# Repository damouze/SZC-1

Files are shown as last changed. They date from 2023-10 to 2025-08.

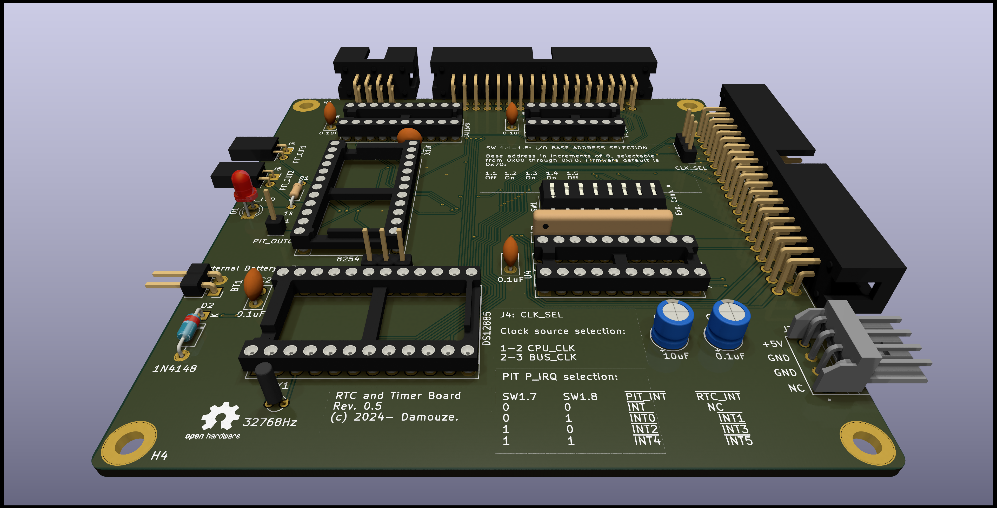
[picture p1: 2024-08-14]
pics/renderings/rtc_timer_board_front.png

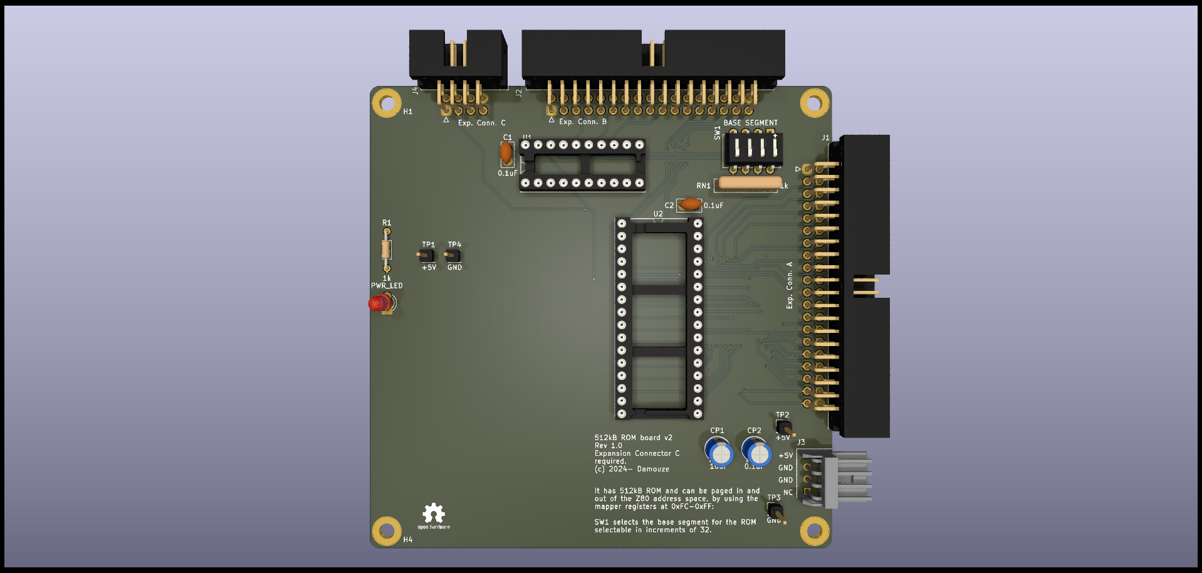
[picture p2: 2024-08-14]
pics/renderings/rom_board_512kB_v2_top.png

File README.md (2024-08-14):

# The Stackable Z80 Computer

A layman's attempt at designing a modular, stackable Z80 computer.

## Disclaimer

Let me start by pointing out that I am not an electronic engineer. Everything I know
about electronics I learned from the internet and from two electronic design courses
during my university days, and nearly all of it is theoretical. I am really more of a
software person who decided at one point in his not-so-distant past that it might be
fun to start learning to design (digital) electronic circuits. 

That said, this is not my first KiCAD project. 

The designs in this repository are bound to have many, many flaws, and I would love to
hear about them from you. Just keep in mind that I do have a day job and that it takes
precedence if I do not respond to them within a day. As a person without an actual
background in electronic design I am sure I am making assumptions about components in
the design that are incorrect or otherwise potentially troublesome. 

Ok, enough ranting. Let's have a look at it.

## Physical description

In principle, the Stackable Z80 computer is more an idea than an actual design. As such
it is built around the following concepts:

- The board dimensions are 95.25mm x 95.25mm (3.75" x 3.75")
- There are four main connectors:
    - Expansion Connector A (2x20 pins, IDC)
	- Expansion Connector B (2x17 pins, IDC)
	- Expansion Connector C (2x4 pins, IDC)
	- Power Connector (2x10 pins, IDC)
- Each board can be stacked on top of another through the use of standoffs

Expansion Connector A is standardized; it contains most, if not all, of the relevant
Z80 signals, such as the address bus (A0-A15), the data bus (D0-D7), control signals
like /INT, /RESET, etc, and both a CPU_CLK and a BUS_CLK signal (they may differ, but
the former should then always be an integer multiple of the latter). All address, data
and control lines should have pull-ups or pull-downs on at least one board, so as to
prevent undesirable current from flowing between two devices asserting the bus at the
same time. They are also buffered. Pins 1 and 40 are connected to ground.

Expansion Connector B is partly standardized; the uneven numbered pins are used for 8
interrupt lines (/INT0-/INT7), as well as 8 more address lines (MA14-A21). Pins 1 and 
34 are connected to ground. The remaining pins, all even, are defined as USER0-USER15,
or in other words, user defined. 

Expansion Connector C contains the extra bus signals provided by the Z80 CPU board with
an extended bus (cpu_board_ext_bus+v2). It provides 5 new signals: /IOR, /IOW, /MEMR, /MEMW
and /INTA. These can be used to simplify the designs of future boards. In addition they
also provide the necessary signals for interfacing with an Intel 8259 Programmable
Interrupt Controller. 

The Power Connector is standardized around the 20-pins ATX power supply connector, and indeed
the Power Board does contain one, but power to the CPU board is provided through an IDC header.
The rationale behind this is that power to the CPU board is is delivered from the power supply 
through the power board, which has a front panel header and which in turn distributes power to
the CPU board through the aforementioned 2x10 pins IDC header.

Power delivery to all other boards is standardized around the old-fashioned floppy 
connector (TE_171826-4). Only +12V and +5V are available. +5VSB (standby power) and 3.3V
should be delivered separately, for instance from the power board.

## Minimal configuration (top to bottom)

- Serial I/O board
- ROM/RAM board
- The "even simpler Z80" board
- Power board V2

This will provide a basic Z80 system with serial I/O support. The serial I/O board should
be configured to use /INT as its interrupt line and use 0x80 as its I/O base address.

The system will have 32kB of ROM, as well as 96kB of RAM, able to be paged in or out of the
Z80 address space as needed in segments of 16kB. 

Expansion Bus B is not used in this configuration.

## A more advance configuration (top to bottom)

- Serial I/O board
- ROM/RAM board v2
- CPU board with expansion Connector C
- Power board V2

This will provide a slightly more advanced Z80 system with serial I/O support. The serial I/O
board should be configured to use /INT as its interrupt line and use 0x80 as its I/O
base address. The ROM/RAM board should be configured for Bank 0. 

This system will have 512kB of Flash ROM and 1536kB of SRAM. Segments 0-31 will be ROM, 
segments 32-127 will be RAM. Segments 128-255 will be available for add-on boards with
their own ROM or RAM or which use memory mapped I/O. 

## Repository layout
 
The repository is laid out as follows:

- boards/core contains the core boards
    - even_simpler_z80: the basic, bare bones Z80 board; just the CPU, some buffers/latches and a clock generator
	- power_board: the power delivery board
	- power_board_v2: and updated version of the power delivery board, with power-on circuitry onboard
	- rom_ram_board: a board that provides 32kB of ROM and 96kB of RAM, able to be paged in and out as needed
	- serial_io_board: a board that provides a RS232 interface for outside communication
- boards/extra contains some extra board designs
    - 8259_pic_board: 8259 Interrupt Controller Board for the SZC-1; requires Expansion Connector C
    - audio_board: SSG Audio Board for the SZC-1, providing SSG sound support
	- cpu_board_ext_bus_v2: new and improved CPU board providing Expansion Connector C and an on-board memory mapper
    - diag_board: a basic diagnostics board, providing a 2-digit 7-segment display accessible through I/O port 0xb8
	- ide_board: IDE Board for the SZC-1, inspired by the Beer IDE interface for the MSX
	- mmu_board: a preliminary design for a Z80 MMU built around a ATF1502/1504 CPLD (*work in progress*)
	- rom_ram_board_2MB: a board that provides 512kB of flash ROM and 1536kB of RAM, able to be paged in and out as needed
	- rom_ram_board_128kB_v2: another board that provides 32kB of EEPROM and 96kB of RAM; requires Expansion Connector C
	- rom_ram_board_v2: another board that provides 512kB of flash ROM and 1536kB of RAM; requires Expansion Connector C
	- simple_z80: the original Z80 board, CPU, buffers/latches and a LS74xx based IM2 interrupt controller
- boards/msx_compat contains boards to provide MSX compatibility (*work in progress*)
    - msx_rom_board: a board that houses to 32kB EEPROM sockets for MSX compatible ROMs (requires the ppi_slot_select_expanded board)
    - msx_rom_ram_board: a board with 512kB flash ROM and 1MB SRAM (requires the ppi_slot_select_expanded board)
	- ppi_slot_select: a board that provides MSX compatible slot select registers as well as 16 GPIO pins
	- ppi_slot_select_expanded: as ppi_slot_select, but also contains an expanded slot select register
- digital contains experiments made in Digital to work out some concepts
- doc: contains documentation and other reference material
- ibom: interactive BOMs for the boards
- pics: 
    - renderings: contains 3D renderings of most of the boards
	- photos: contains photos of PCBs and assembled boards
- verilog: contains verilog output from Digital for the experiments in the *digital* folder.

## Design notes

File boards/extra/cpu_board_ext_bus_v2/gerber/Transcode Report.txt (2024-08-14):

   ---- Transcoding 'C:\Users\dmouse\ownCloud\Projects\KiCAD\SZC-1\boards\extra\cpu_board_ext_bus_v2\gerber\cpu_board_ext_bus_v2-B_Cu.gbr' ----   Fri May 10 12:37:28 2024

D28   --> D100
D29   --> D101
-----------------------------------------------------------------

   ---- Transcoding 'C:\Users\dmouse\ownCloud\Projects\KiCAD\SZC-1\boards\extra\cpu_board_ext_bus_v2\gerber\cpu_board_ext_bus_v2-F_Silkscreen.gbr' ----   Fri May 10 12:37:28 2024

D11   --> D102
D12   --> D103
D13   --> D104
-----------------------------------------------------------------

   ---- Transcoding 'C:\Users\dmouse\ownCloud\Projects\KiCAD\SZC-1\boards\extra\cpu_board_ext_bus_v2\gerber\cpu_board_ext_bus_v2-User_Comments.gbr' ----   Fri May 10 12:37:28 2024

D10   --> D105
-----------------------------------------------------------------

   ---- Transcoding 'C:\Users\dmouse\ownCloud\Projects\KiCAD\SZC-1\boards\extra\cpu_board_ext_bus_v2\gerber\cpu_board_ext_bus_v2-Edge_Cuts.gbr' ----   Fri May 10 12:37:28 2024

D10   --> D106
-----------------------------------------------------------------

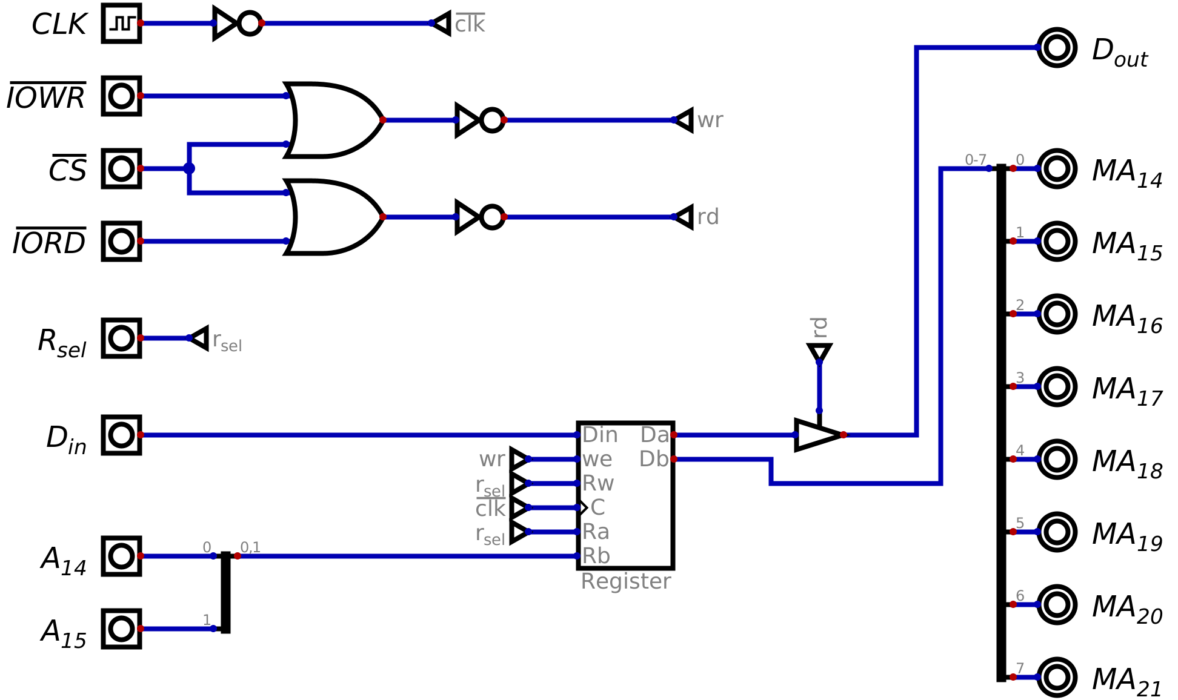
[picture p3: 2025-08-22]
pics/renderings/z80_mmu.png

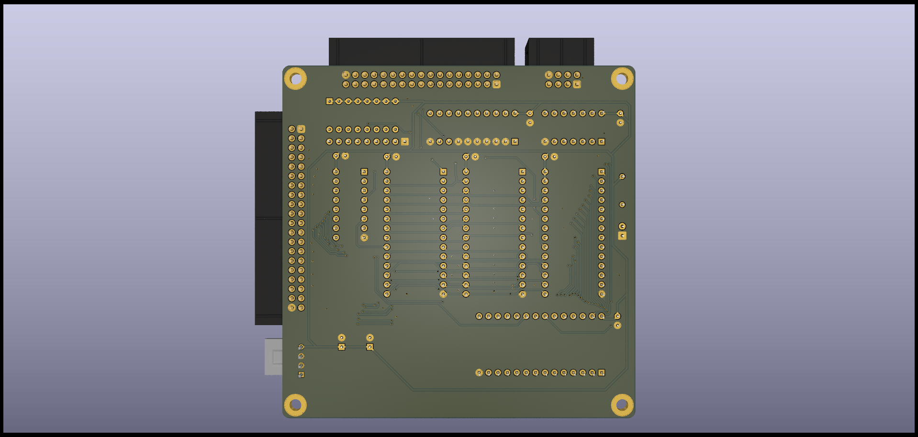
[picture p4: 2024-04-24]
pics/renderings/rom_ram_board_128kB_v2_bottom.png

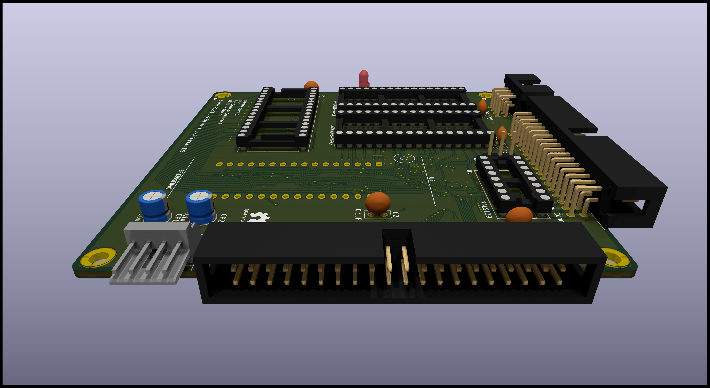
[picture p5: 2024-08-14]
pics/renderings/rom_ram_board_v3_right.png

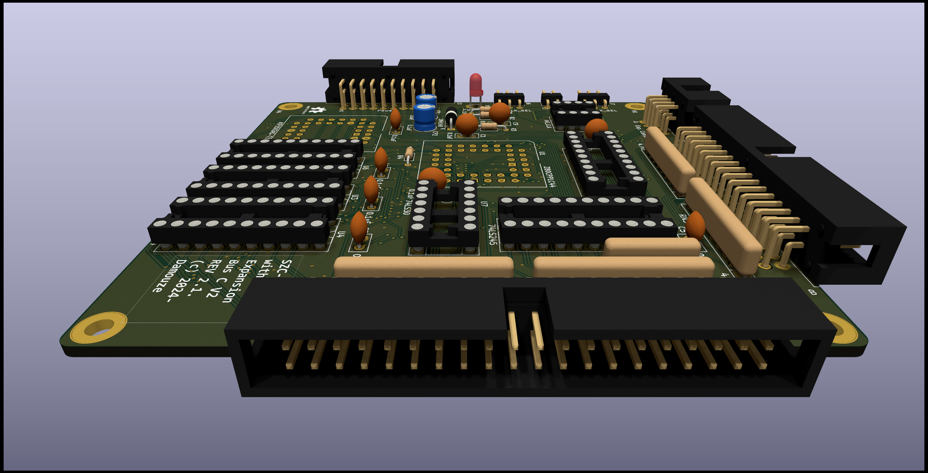
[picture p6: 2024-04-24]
pics/renderings/cpu_board_ext_bus_v2_right.png

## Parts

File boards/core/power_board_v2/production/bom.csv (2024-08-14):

Designator | Footprint | Quantity | Value | LCSC Part #
D1 | LED_D3.0mm | 1 | PWR_LED
D2 | LED_D3.0mm | 1 | SB_LED
H1, H2, H3, H4 | MountingHole_3.2mm_M3_ISO7380_Pad | 4 | MountingHole_Pad
J1 | IDC-Header_2x20_P2.54mm_Horizontal | 1 | Exp. Conn. A
J2 | IDC-Header_2x17_P2.54mm_Horizontal | 1 | Exp. Conn. B
J3 | IDC-Header_2x10_P2.54mm_Horizontal | 1 | Power
J4 | PinHeader_2x06_P2.54mm_Horizontal | 1 | Front Panel Connector
J5 | Molex_Mini-Fit_Jr_5569-20A1_2x10_P4.20mm_Horizontal | 1 | ATX-20
R1, R2, R3 | R_Axial_DIN0204_L3.6mm_D1.6mm_P7.62mm_Horizontal | 3 | 470

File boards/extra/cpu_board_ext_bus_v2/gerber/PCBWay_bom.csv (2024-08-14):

designator | quantity | value | pack | mpn | mount_type
C1, C2, C3, C4, C5, C6, C7, C8, C9 | 9 | 0.1uF | C_Disc_D5.0mm_W2.5mm_P2.50mm | FG28X7R1H104KNT06 | tht
CP1 | 1 | 10uF | CP_Radial_D5.0mm_P2.50mm | ECA1HM100I | tht
CP2 | 1 | 0.1uF | CP_Radial_D5.0mm_P2.50mm | KS104M050C07RR0VH2FP0 | tht
D1 | 1 | PWR_LED | LED_D3.0mm | HLMP-1700 | tht
D2 | 1 | 1N4148 | D_DO-35_SOD27_P7.62mm_Horizontal | 1N4148TA | tht
H1, H2, H3, H4 | 4 | MountingHole_Pad | MountingHole_3.2mm_M3_ISO7380_Pad |  | tht
J1 | 1 | Exp. Conn. A | IDC-Header_2x20_P2.54mm_Horizontal | X9555WR-2x20-6TV01 | tht
J2 | 1 | Exp. Conn. B | IDC-Header_2x17_P2.54mm_Horizontal | X9555WR-2x17-6TV01 | tht
J3 | 1 | Power | IDC-Header_2x10_P2.54mm_Horizontal | X9555WR-2x10-6TV01 | tht
J4 | 1 | Exp. Conn. C | IDC-Header_2x04_P2.54mm_Horizontal | 75867-132LF | tht
J5 | 1 | EXT_CLK | PinHeader_1x02_P2.54mm_Horizontal | PZ254R-11-02P | tht
J6 | 1 | CPU_CLK_SEL | PinHeader_1x03_P2.54mm_Horizontal | PZ254R-11-03P | tht
J7 | 1 | BUS_CLK_SEL | PinHeader_1x03_P2.54mm_Horizontal | PZ254R-11-03P | tht
R1 | 1 | 1k | R_Axial_DIN0204_L3.6mm_D1.6mm_P7.62mm_Horizontal | MFR2WSFTE73-1K | tht
R2, R3 | 2 | 10k | R_Axial_DIN0204_L3.6mm_D1.6mm_P7.62mm_Horizontal | MFR3WSFTE73-10K | tht
R4 | 1 | 4.7k | R_Axial_DIN0204_L3.6mm_D1.6mm_P7.62mm_Horizontal | MF0207FTE52-4K7 | tht
RN1, RN2, RN3, RN4 | 4 | 4.7k | R_Array_SIP9 | A09-472JP | tht
RN5 | 1 | 4.7k | R_Array_SIP5 | A05-472JP | tht
U1 | 1 | Z80CPPLC44 | PLCC-44_THT-Socket | DS1032-44SDKT1A | tht
U2 | 1 | GAL16V8 | DIP-20_W7.62mm_Socket | 1-2199298-6 | tht
U3, U4, U6 | 3 | 74LS244 | DIP-20_W7.62mm_Socket | 1-2199298-6 | tht
U5 | 1 | 74LS245 | DIP-20_W7.62mm_Socket | 1-2199298-6 | tht
U7 | 1 | 74LS30 | DIP-14_W7.62mm_Socket | 1-2199298-3 | tht
U8 | 1 | ATF1502AS-7JX44 | PLCC-44_THT-Socket | DS1032-44SDKT1A | tht
X1 | 1 | INT_CLK | DIP-8_W7.62mm_Socket | 1-2199298-2 | tht

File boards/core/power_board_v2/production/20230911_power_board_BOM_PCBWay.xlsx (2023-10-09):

 |  |  | xxxx xxxx xxxxx xxPCS BOM (Sample Bill of Materials)
Item # | *Designator | *Qty | Manufacturer | *Mfg Part # | Description / Value | *Package/Footprint | Type | Your Instructions / Notes
1 | D1 | 1 | Broadcom/AVAGO | HLMP-1700 | -40℃~+100℃ 626nm Red 14mW Plugin,D=3.2mm Light Emitting Diodes (LED) ROHS | LED_D3.0mm | thru-hole
2 | D2 | 1 | Broadcom/AVAGO | HLMP-1700 | -40℃~+100℃ 626nm Red 14mW Plugin,D=3.2mm Light Emitting Diodes (LED) ROHS | LED_D3.0mm | thru-hole
3 | H1, H2, H3, H4 | 4 | N/A | N/A | MountingHole_3.2mm_M3_ISO7380_Pad | N/A | N/A | Part of the board layout
4 | J1 | 1 | XKB Connectivity | X9555WR-2x20-6TV01 | 2x20P 2 Gold 2.54mm Male pin 2.54mm 20 260℃ -25℃~+85℃ Brass 3A Shrouded Push-Pull,P=2.54mm Wire To Board / Wire To Wire Connector ROHS | IDC-Header_2x20_P2.54mm_Horizontal | thru-hole
5 | J2 | 1 | XKB Connectivity | X9555WR-2x17-6TV01 | 2x17P 2 Gold 2.54mm Male pin 2.54mm 17 260℃ -25℃~+85℃ Brass 3A Shrouded Push-Pull,P=2.54mm Wire To Board / Wire To Wire Connector ROHS | IDC-Header_2x17_P2.54mm_Horizontal | thru-hole
6 | J3 | 1 | XKB Connectivity | X9555WR-2x10-6TV01 | 2x10P 2 Gold 2.54mm Male pin 2.54mm 10 260℃ -25℃~+85℃ Brass 3A Shrouded Push-Pull,P=2.54mm Wire To Board / Wire To Wire Connector ROHS | IDC-Header_2x10_P2.54mm_Horizontal | thru-hole
7 | J4 | 1 | XFCN | PZ254R-12-12P | Shrouded Square Pins 2.5mm 12P 6mm -40℃~+105℃ 2.54mm 双排 Black Brass 2x6P 2.54mm Push-Pull,P=2.54mm Pin Headers ROHS | PinHeader_2x06_P2.54mm_Horizontal | thru-hole
8 | J5 | 1 | Molex | 39301200 | 2x10P 2 4.2mm Female pin 4.2mm 10 Shrouded Push-Pull,P=4.2mm Wire To Board / Wire To Wire Connector ROHS | Molex_Mini-Fit_Jr_5569-20A1_2x10_P4.20mm_Horizontal | thru-hole
9 | R1, R2, R3 | 3 | YAGEO | MFR-25FRF52-1K | Metal Film Resistors 1kΩ 250mW ±100ppm/℃ ±1% Plugin Through Hole Resistors ROHS | R_Axial_DIN0204_L3.6mm_D1.6mm_P7.62mm_Horizontal | thru-hole
10
11
12
13
14
15
Need a quick and accurante quote? Need an efficient production? Please read SMT Ordering Necessary Files & Info in 1 minute. Thank you very much! (https://www.pcbway.com/smt_ordering_guide.html)
Click for Instructions on How to Create a BOM (https://www.pcbway.com/blog/PCB_Assembly/How_to_Build_a_BOM__Bill_Of_Materials_.html)

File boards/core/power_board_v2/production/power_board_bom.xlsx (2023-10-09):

Designator | Footprint | Quantity | Value | LCSC Part # | DIGIKEY Part # | LCSC Piece Price | Digikey Piece Price | PCBWay Piece Price | LCSC Price | Digikey Price | PCBWay Price
D1 | LED_D3.0mm | 1 | PWR_LED | C188720 | 516-1308-ND | €0.59 | €0.59 |  | €0.59 | €0.59
D2 | LED_D3.0mm | 1 | SB_LED | C188720 | 516-1308-ND | €0.59 | €0.59 |  | €0.59 | €0.59
H1, H2, H3, H4 | MountingHole_3.2mm_M3_ISO7380_Pad | 4 | MountingHole_Pad | N/A | N/A |  |  |  | €0.00 | €0.00
J1 | IDC-Header_2x20_P2.54mm_Horizontal | 1 | Exp. Conn. A | C2682225 | 609-3345-ND | €0.41 | €1.29 |  | €0.41 | €1.29
J2 | IDC-Header_2x17_P2.54mm_Horizontal | 1 | Exp. Conn. B | C2682224 | A97489-ND | €0.35 | €3.60 |  | €0.35 | €3.60
J3 | IDC-Header_2x10_P2.54mm_Horizontal | 1 | Power | C2884508 | A33184-ND | €0.21 | €2.50 |  | €0.21 | €2.50
J4 | PinHeader_2x06_P2.54mm_Horizontal | 1 | Front Panel Connector | C492434 | 9-103326-0-06 | €0.07 | €1.22 |  | €0.07 | €1.22
J5 | Molex_Mini-Fit_Jr_5569-20A1_2x10_P4.20mm_Horizontal | 1 | ATX-20 | C485578 | WM1360-ND | €2.75 | €3.31 |  | €2.75 | €3.31
R1, R2, R3 | R_Axial_DIN0204_L3.6mm_D1.6mm_P7.62mm_Horizontal | 3 | 1k | C3424075 | 13-MFR-25FRF52-1KCT-ND | €0.01 | €0.09 |  | €0.04 | €0.27
Component Cost |  |  |  |  |  |  |  |  | €15.03
PCB Production |  | 5 |  |  |  |  |  | €1.00 |  |  | €5.00
PCB Assembly |  | 3 |  |  |  |  |  | €10.00 |  |  | €30.00
TOTAL w. LCSC Parts |  |  |  |  |  |  |  |  | €50.03
TOTAL w. Digikey Parts |  |  |  |  |  |  |  |  |  | €75.11
Costs per assembled board |  |  |  |  |  |  |  |  | €16.68 | €25.04

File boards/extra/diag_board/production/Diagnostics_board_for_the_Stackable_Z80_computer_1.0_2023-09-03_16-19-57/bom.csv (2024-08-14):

Designator | Footprint | Quantity | Value | LCSC Part #
C1, C2, C3, C4, C5, C6, C7 | C_Disc_D5.0mm_W2.5mm_P2.50mm | 7 | 0.1uF
CP1 | CP_Radial_D5.0mm_P2.50mm | 1 | 10uF
CP2 | CP_Radial_D5.0mm_P2.50mm | 1 | 0.1uF
D1 | LED_D3.0mm | 1 | PWR_LED
D10 | LED_D3.0mm | 1 | LED_12V
D11 | LED_D3.0mm | 1 | LED_-12V
D2 | LED_D3.0mm | 1 | LED_3.3V
D3, D4 | LED_D3.0mm | 2 | LED_3.3V2
D5 | LED_D3.0mm | 1 | LED_5V
D6 | LED_D3.0mm | 1 | LED_5V2
D7 | LED_D3.0mm | 1 | LED_5V3
D8 | LED_D3.0mm | 1 | LED_5V4
D9 | LED_D3.0mm | 1 | LED_5VSB
H1, H2, H3, H4 | MountingHole_3.2mm_M3_ISO7380_Pad | 4 | MountingHole_Pad
J1 | IDC-Header_2x20_P2.54mm_Horizontal | 1 | Exp. Conn. A
J3 | IDC-Header_2x10_P2.54mm_Horizontal | 1 | Power
J4 | PinHeader_2x10_P2.54mm_Horizontal | 1 | 7SEG_LED_DISPLAY
R1 | R_Axial_DIN0204_L3.6mm_D1.6mm_P7.62mm_Horizontal | 1 | 470
R10, R11 | R_Axial_DIN0204_L3.6mm_D1.6mm_P7.62mm_Horizontal | 2 | 2.4k
R2, R3, R4 | R_Axial_DIN0204_L3.6mm_D1.6mm_P7.62mm_Horizontal | 3 | 660
R5, R6, R7, R8, R9 | R_Axial_DIN0204_L3.6mm_D1.6mm_P7.62mm_Horizontal | 5 | 1k
RN1, RN2 | R_Array_SIP5 | 2 | 1k
U1 | DIP-20_W7.62mm_Socket | 1 | 74LS688
U2 | DIP-14_W7.62mm_Socket | 1 | 74LS04
U3 | DIP-14_W7.62mm_Socket | 1 | 74LS74
U4 | DIP-14_W7.62mm_Socket | 1 | 74LS02
U5 | DIP-20_W7.62mm_Socket | 1 | 74LS573
U6, U7 | DIP-20_W7.62mm_Socket | 2 | GAL16V8

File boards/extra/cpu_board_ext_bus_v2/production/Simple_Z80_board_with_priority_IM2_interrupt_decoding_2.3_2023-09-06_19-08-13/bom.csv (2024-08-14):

Designator | Footprint | Quantity | Value | LCSC Part #
C1, C10, C12, C2, C3, C4, C5, C6, C7, C8, C9 | C_Disc_D5.0mm_W2.5mm_P2.50mm | 11 | 0.1uF
CP1 | CP_Radial_D5.0mm_P2.50mm | 1 | 10uF
CP2 | CP_Radial_D5.0mm_P2.50mm | 1 | 0.1uF
D1 | LED_D3.0mm | 1 | PWR_LED
D2 | D_A-405_P7.62mm_Horizontal | 1 | D
H1, H2, H3, H4 | MountingHole_3.2mm_M3_ISO7380_Pad | 4 | MountingHole_Pad
J1 | IDC-Header_2x20_P2.54mm_Horizontal | 1 | Exp. Conn. A
J2 | IDC-Header_2x17_P2.54mm_Horizontal | 1 | Exp. Conn. B
J3 | IDC-Header_2x10_P2.54mm_Horizontal | 1 | Power
J4 | PinHeader_1x02_P2.54mm_Horizontal | 1 | EXT_CLK
J5 | PinHeader_1x03_P2.54mm_Horizontal | 1 | CPU_CLK_SEL
J6 | PinHeader_1x03_P2.54mm_Horizontal | 1 | BUS_CLK_SEL
R1 | R_Axial_DIN0204_L3.6mm_D1.6mm_P7.62mm_Horizontal | 1 | 470
R2, R3 | R_Axial_DIN0204_L3.6mm_D1.6mm_P7.62mm_Horizontal | 2 | 10k
RN1, RN2, RN3, RN4 | R_Array_SIP9 | 4 | 4.7k
RN5 | R_Array_SIP5 | 1 | 4.7k
U1 | DIP-14_W7.62mm_Socket | 1 | 74LS32
U10 | DIP-20_W7.62mm_Socket | 1 | 74LS245
U2 | DIP-16_W7.62mm_Socket | 1 | 74LS148
U3 | DIP-20_W7.62mm_Socket | 1 | 74LS573
U4 | DIP-14_W7.62mm_Socket | 1 | 74LS04
U5 | PLCC-44_THT-Socket | 1 | Z80CPPLC44
U6 | DIP-14_W7.62mm_Socket | 1 | 74LS08
U7, U8, U9 | DIP-20_W7.62mm_Socket | 3 | 74LS244
X1 | DIP-8_W7.62mm_Socket | 1 | INT_CLK

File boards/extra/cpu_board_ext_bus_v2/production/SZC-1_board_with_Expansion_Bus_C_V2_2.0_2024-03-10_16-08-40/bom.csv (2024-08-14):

Designator | Footprint | Quantity | Value | LCSC Part #
C1, C2, C3, C4, C5, C6, C7, C8, C9 | C_Disc_D5.0mm_W2.5mm_P2.50mm | 9 | 0.1uF
CP1 | CP_Radial_D5.0mm_P2.50mm | 1 | 10uF
CP2 | CP_Radial_D5.0mm_P2.50mm | 1 | 0.1uF
D1 | LED_D3.0mm | 1 | PWR_LED
D2 | D_A-405_P7.62mm_Horizontal | 1 | 1N4148
H1, H2, H3, H4 | MountingHole_3.2mm_M3_ISO7380_Pad | 4 | MountingHole_Pad
J1 | IDC-Header_2x20_P2.54mm_Horizontal | 1 | Exp. Conn. A
J2 | IDC-Header_2x17_P2.54mm_Horizontal | 1 | Exp. Conn. B
J3 | IDC-Header_2x10_P2.54mm_Horizontal | 1 | Power
J4 | IDC-Header_2x04_P2.54mm_Horizontal | 1 | Exp. Conn. C
J5 | PinHeader_1x02_P2.54mm_Horizontal | 1 | EXT_CLK
J6 | PinHeader_1x03_P2.54mm_Horizontal | 1 | CPU_CLK_SEL
J7 | PinHeader_1x03_P2.54mm_Horizontal | 1 | BUS_CLK_SEL
R1 | R_Axial_DIN0204_L3.6mm_D1.6mm_P7.62mm_Horizontal | 1 | 1k
R2, R3 | R_Axial_DIN0204_L3.6mm_D1.6mm_P7.62mm_Horizontal | 2 | 10k
R4 | R_Axial_DIN0204_L3.6mm_D1.6mm_P7.62mm_Horizontal | 1 | 4.7k
RN1, RN2, RN3, RN4 | R_Array_SIP9 | 4 | 4.7k
RN5 | R_Array_SIP5 | 1 | 4.7k
U1 | PLCC-44_THT-Socket | 1 | Z80CPPLC44
U2 | DIP-20_W7.62mm_Socket | 1 | GAL16V8
U3, U4, U6 | DIP-20_W7.62mm_Socket | 3 | 74LS244
U5 | DIP-20_W7.62mm_Socket | 1 | 74LS245
U7 | DIP-14_W7.62mm_Socket | 1 | 74LS30
U8 | PLCC-44_THT-Socket | 1 | ATF1502AS-7JX44
X1 | DIP-8_W7.62mm_Socket | 1 | INT_CLK

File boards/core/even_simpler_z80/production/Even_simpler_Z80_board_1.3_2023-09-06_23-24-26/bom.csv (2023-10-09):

Designator | Footprint | Quantity | Value | LCSC Part #
C1, C10, C2, C3, C4, C5, C6, C7, C8 | C_Disc_D5.0mm_W2.5mm_P2.50mm | 9 | 0.1uF
CP1 | CP_Radial_D5.0mm_P2.50mm | 1 | 10uF
CP2 | CP_Radial_D5.0mm_P2.50mm | 1 | 0.1uF
D1 | LED_D3.0mm | 1 | PWR_LED
D2 | D_A-405_P7.62mm_Horizontal | 1 | 1N4148
H1, H2, H3, H4 | MountingHole_3.2mm_M3_ISO7380_Pad | 4 | MountingHole_Pad
J1 | IDC-Header_2x20_P2.54mm_Horizontal | 1 | Exp. Conn. A
J2 | IDC-Header_2x17_P2.54mm_Horizontal | 1 | Exp. Conn. B
J3 | IDC-Header_2x10_P2.54mm_Horizontal | 1 | Power
J4 | PinHeader_1x02_P2.54mm_Horizontal | 1 | EXT_CLK
J5 | PinHeader_1x03_P2.54mm_Horizontal | 1 | CPU_CLK_SEL
J6 | PinHeader_1x03_P2.54mm_Horizontal | 1 | BUS_CLK_SEL
R1 | R_Axial_DIN0204_L3.6mm_D1.6mm_P7.62mm_Horizontal | 1 | 1k
R2, R3 | R_Axial_DIN0204_L3.6mm_D1.6mm_P7.62mm_Horizontal | 2 | 10k
RN1, RN2, RN3, RN4 | R_Array_SIP9 | 4 | 4.7k
RN5 | R_Array_SIP5 | 1 | 4.7k
U1 | PLCC-44_THT-Socket | 1 | Z80CPPLC44
U2 | DIP-14_W7.62mm_Socket | 1 | 74LS32
U3, U5, U6 | DIP-20_W7.62mm_Socket | 3 | 74LS244
U4 | DIP-14_W7.62mm_Socket | 1 | 74LS04
U7 | DIP-14_W7.62mm_Socket | 1 | 74LS08
U8 | DIP-20_W7.62mm_Socket | 1 | 74LS245
X1 | DIP-8_W7.62mm_Socket | 1 | INT_CLK

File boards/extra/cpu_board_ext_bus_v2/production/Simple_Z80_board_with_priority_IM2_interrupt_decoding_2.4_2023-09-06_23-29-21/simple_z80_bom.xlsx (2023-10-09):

Designator | Footprint | Quantity | Value | LCSC Part # | Digikey Part #
C1, C10, C12, C2, C3, C4, C5, C6, C7, C8, C9 | C_Disc_D5.0mm_W2.5mm_P2.50mm | 11 | 0.1uF | C444742 | 478-7358-1-ND
CP1 | CP_Radial_D5.0mm_P2.50mm | 1 | 10uF
CP2 | CP_Radial_D5.0mm_P2.50mm | 1 | 0.1uF
D1 | LED_D3.0mm | 1 | PWR_LED | C188720 | 516-1308-ND
D2 | D_A-405_P7.62mm_Horizontal | 1 | 1N4148 | C258182 | 1N4148FS-ND
H1, H2, H3, H4 | MountingHole_3.2mm_M3_ISO7380_Pad | 4 | MountingHole_Pad | N/A | N/A
J1 | IDC-Header_2x20_P2.54mm_Horizontal | 1 | Exp. Conn. A | C2682225 | 609-3345-ND
J2 | IDC-Header_2x17_P2.54mm_Horizontal | 1 | Exp. Conn. B | C2682224 | A97489-ND
J3 | IDC-Header_2x10_P2.54mm_Horizontal | 1 | Power | C2884508 | A33184-ND
J4 | PinHeader_1x02_P2.54mm_Horizontal | 1 | EXT_CLK
J5 | PinHeader_1x03_P2.54mm_Horizontal | 1 | CPU_CLK_SEL
J6 | PinHeader_1x03_P2.54mm_Horizontal | 1 | BUS_CLK_SEL
R1 | R_Axial_DIN0204_L3.6mm_D1.6mm_P7.62mm_Horizontal | 1 | 1k | C3424075 | 13-MFR-25FRF52-1KCT-ND
R2, R3 | R_Axial_DIN0204_L3.6mm_D1.6mm_P7.62mm_Horizontal | 2 | 10k | C172967 | 13-MFR-25FTE52-10KCT-ND
RN1, RN2, RN3, RN4 | R_Array_SIP9 | 4 | 4.7k | C9112 | 4609M-101-472LF
RN5 | R_Array_SIP5 | 1 | 4.7k | C11392 | 770-61-R4.7KP-ND
U1 | DIP-14_W7.62mm_Socket | 1 | 74LS32 | C2325 | 1175-1476-ND
U10 | DIP-20_W7.62mm_Socket | 1 | 74LS245 | C2328 | 1175-1479-ND
U2 | DIP-16_W7.62mm_Socket | 1 | 74LS148 | C2326 | 1175-1477-ND
U3 | DIP-20_W7.62mm_Socket | 1 | 74LS573 | C2328 | 1175-1479-ND
U4 | DIP-14_W7.62mm_Socket | 1 | 74LS04 | C2325 | 1175-1476-ND
U5 | PLCC-44_THT-Socket | 1 | Z80CPPLC44 | C2326 | 1175-1477-ND
U6 | DIP-14_W7.62mm_Socket | 1 | 74LS08 | C2325 | 1175-1476-ND
U7, U8, U9 | DIP-20_W7.62mm_Socket | 3 | 74LS244 | C2328 | 1175-1479-ND
X1 | DIP-8_W7.62mm_Socket | 1 | INT_CLK | C2325 | 1175-1476-ND

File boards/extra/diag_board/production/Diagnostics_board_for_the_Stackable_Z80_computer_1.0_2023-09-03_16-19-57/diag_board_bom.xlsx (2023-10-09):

Designator | Footprint | Quantity | Value | LCSC Part # | Digikey Part #
C1, C2, C3, C4, C5, C6, C7 | C_Disc_D5.0mm_W2.5mm_P2.50mm | 7 | 0.1uF | C444742 | 478-7358-1-ND
CP1 | CP_Radial_D5.0mm_P2.50mm | 1 | 10uF
CP2 | CP_Radial_D5.0mm_P2.50mm | 1 | 0.1uF
D1 | LED_D3.0mm | 1 | PWR_LED | C188720 | 516-1308-ND
D10 | LED_D3.0mm | 1 | LED_12V | C188720 | 516-1308-ND
D11 | LED_D3.0mm | 1 | LED_-12V | C188720 | 516-1308-ND
D2 | LED_D3.0mm | 1 | LED_3.3V | C188720 | 516-1308-ND
D3, D4 | LED_D3.0mm | 2 | LED_3.3V2 | C188720 | 516-1308-ND
D5 | LED_D3.0mm | 1 | LED_5V | C188720 | 516-1308-ND
D6 | LED_D3.0mm | 1 | LED_5V2 | C188720 | 516-1308-ND
D7 | LED_D3.0mm | 1 | LED_5V3 | C188720 | 516-1308-ND
D8 | LED_D3.0mm | 1 | LED_5V4 | C188720 | 516-1308-ND
D9 | LED_D3.0mm | 1 | LED_5VSB | C188720 | 516-1308-ND
H1, H2, H3, H4 | MountingHole_3.2mm_M3_ISO7380_Pad | 4 | MountingHole_Pad | N/A | N/A
J1 | IDC-Header_2x20_P2.54mm_Horizontal | 1 | Exp. Conn. A | C2682225 | 609-3345-ND
J3 | IDC-Header_2x10_P2.54mm_Horizontal | 1 | Power | C2884508 | A33184-ND
J4 | PinHeader_2x10_P2.54mm_Horizontal | 1 | 7SEG_LED_DISPLAY
R10, R11 | R_Axial_DIN0204_L3.6mm_D1.6mm_P7.62mm_Horizontal | 2 | 2.4k | C172998 | 13-MFR-25FTE52-2K4CT-ND
R2, R3, R4 | R_Axial_DIN0204_L3.6mm_D1.6mm_P7.62mm_Horizontal | 3 | 660 | C1369260 | 665XBK-ND
R1,R5, R6, R7, R8, R9 | R_Axial_DIN0204_L3.6mm_D1.6mm_P7.62mm_Horizontal | 5 | 1k | C3424075 | 13-MFR-25FRF52-1KCT-ND
RN1, RN2 | R_Array_SIP5 | 2 | 1k | C11389 | 4605X-101-102LF-ND
U1 | DIP-20_W7.62mm_Socket | 1 | 74LS688 | C2328 | 1175-1479-ND
U2 | DIP-14_W7.62mm_Socket | 1 | 74LS04 | C2325 | 1175-1476-ND
U3 | DIP-14_W7.62mm_Socket | 1 | 74LS74 | C2325 | 1175-1476-ND
U4 | DIP-14_W7.62mm_Socket | 1 | 74LS02 | C2325 | 1175-1476-ND
U5 | DIP-20_W7.62mm_Socket | 1 | 74LS573 | C2328 | 1175-1479-ND
U6, U7 | DIP-20_W7.62mm_Socket | 2 | GAL16V8 | C2328 | 1175-1479-ND

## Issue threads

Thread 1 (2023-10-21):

Power delivery may be a problem

damouze, 2023-10-21:
When I started designing these boards, I envisioned them being interconnected through ribbon cables and IDC connectors. That included power. This resulted in the power board as found in this repository.

However, with all the current flowing between the ATX-20 and IDC connectors through traces on a PCB, actual power delivery may become an issue as more and more boards are added to the stack. I'm also not entirely sure how much current a ribbon cable may be able to handle.

I may need to adapt each board to hold an old-fashioned Molex connector. What is now called the "power board" would then only be required to power the CPU board and for the power switch itself. It could even become obsolete if it turns out to be possible to integrate the ATX-20 connector on the CPU boards itself. However, the remaining space on those boards is very limited, so it is far from certain.

damouze, 2024-03-14:
With the exception of the power board itself and any of the CPU boards, all other boards have been adapted to or designed with the floppy drive connector as its power delivery method.

Closed 2024-03-14.

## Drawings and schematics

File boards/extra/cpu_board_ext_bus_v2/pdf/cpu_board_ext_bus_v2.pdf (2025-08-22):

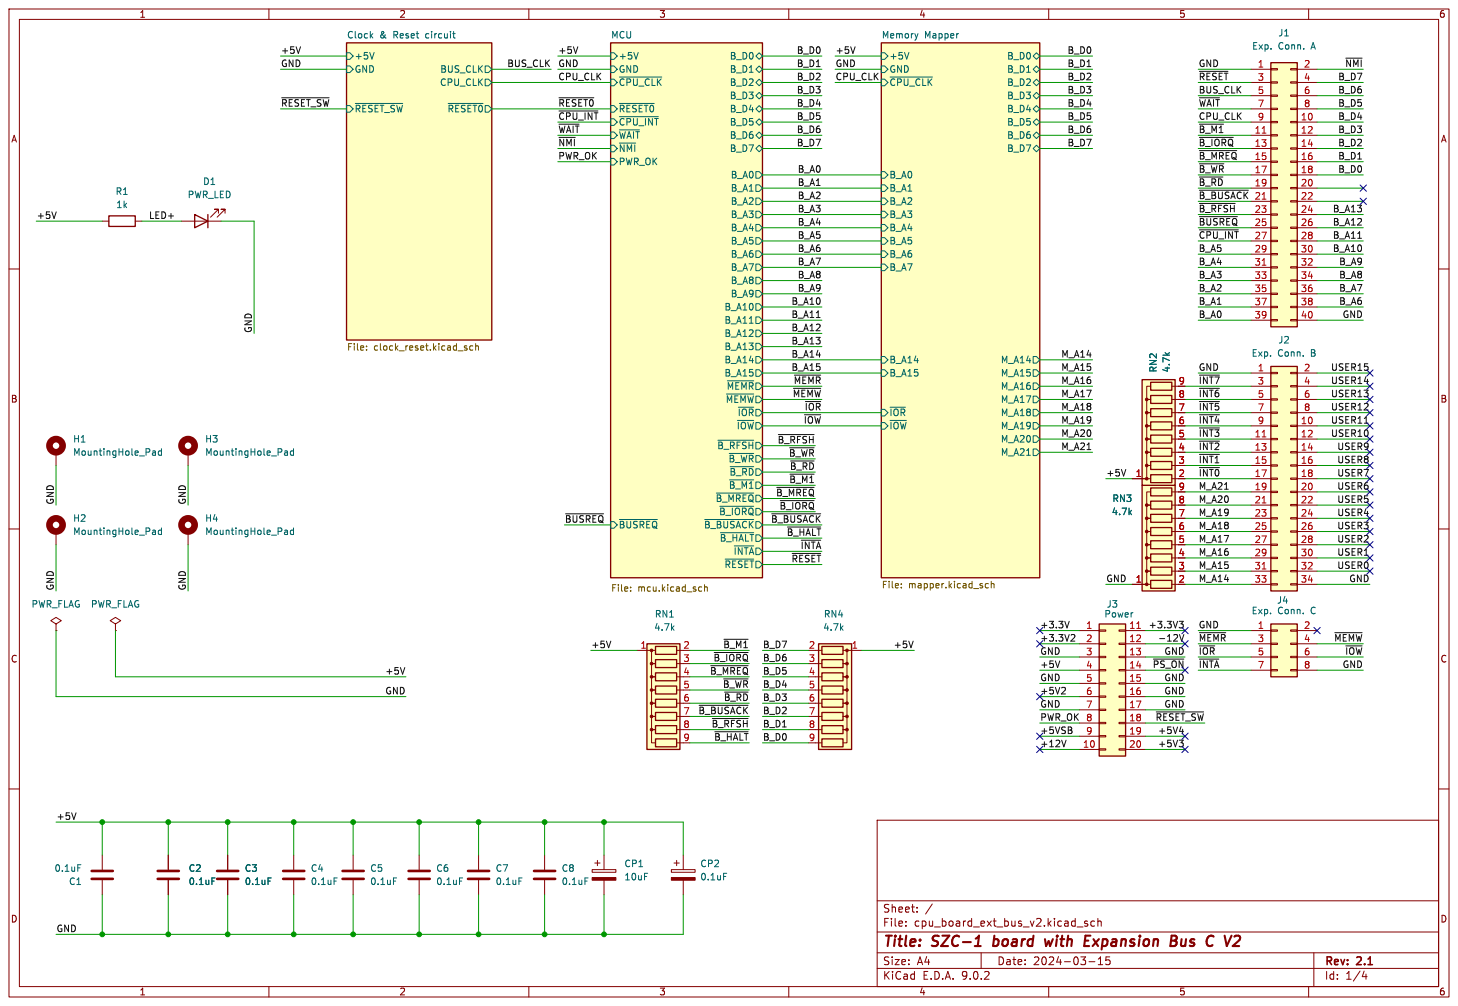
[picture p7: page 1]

~{RESET0} Clock & Reset circuit File: clock_reset.kicad_sch

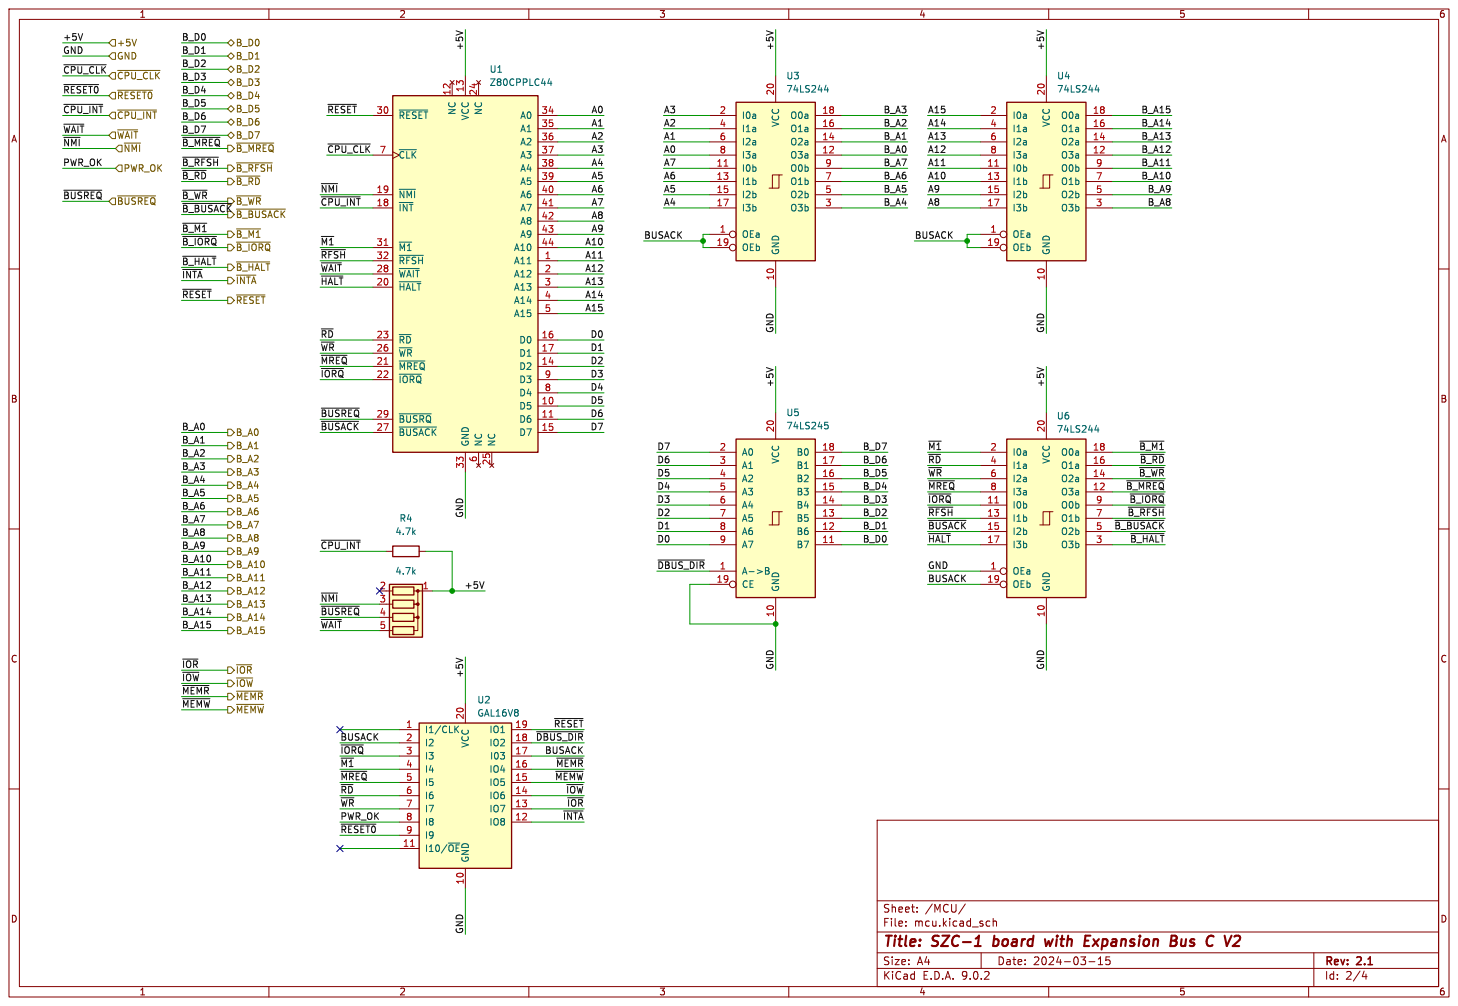
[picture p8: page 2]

File: mcu.kicad_sch Sheet: /MCU/

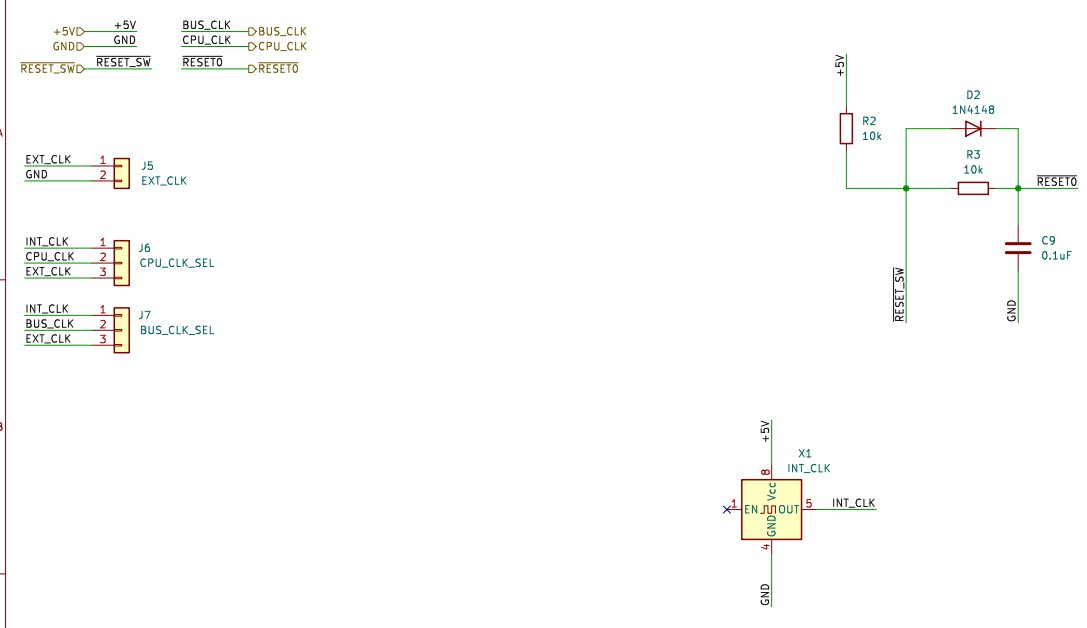
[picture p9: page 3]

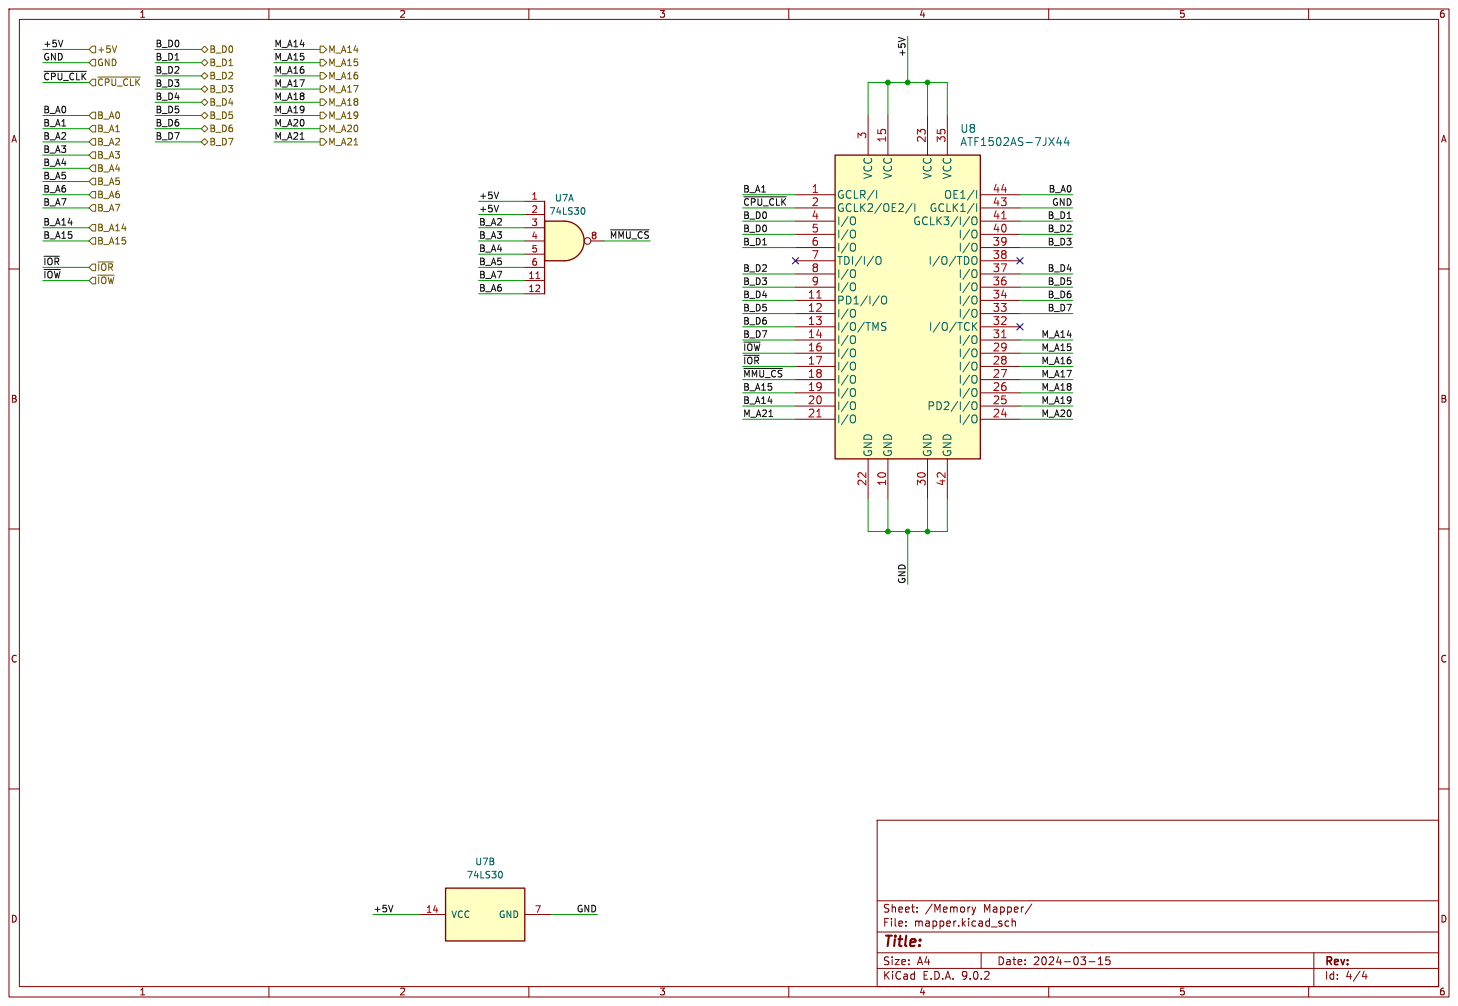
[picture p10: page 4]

3 GND 22 VCC 15 GND 10 VCC 23 GND 30 VCC 35 GND 42 OE1/I 44 GCLK1/I 43 GCLK3/I/O 41

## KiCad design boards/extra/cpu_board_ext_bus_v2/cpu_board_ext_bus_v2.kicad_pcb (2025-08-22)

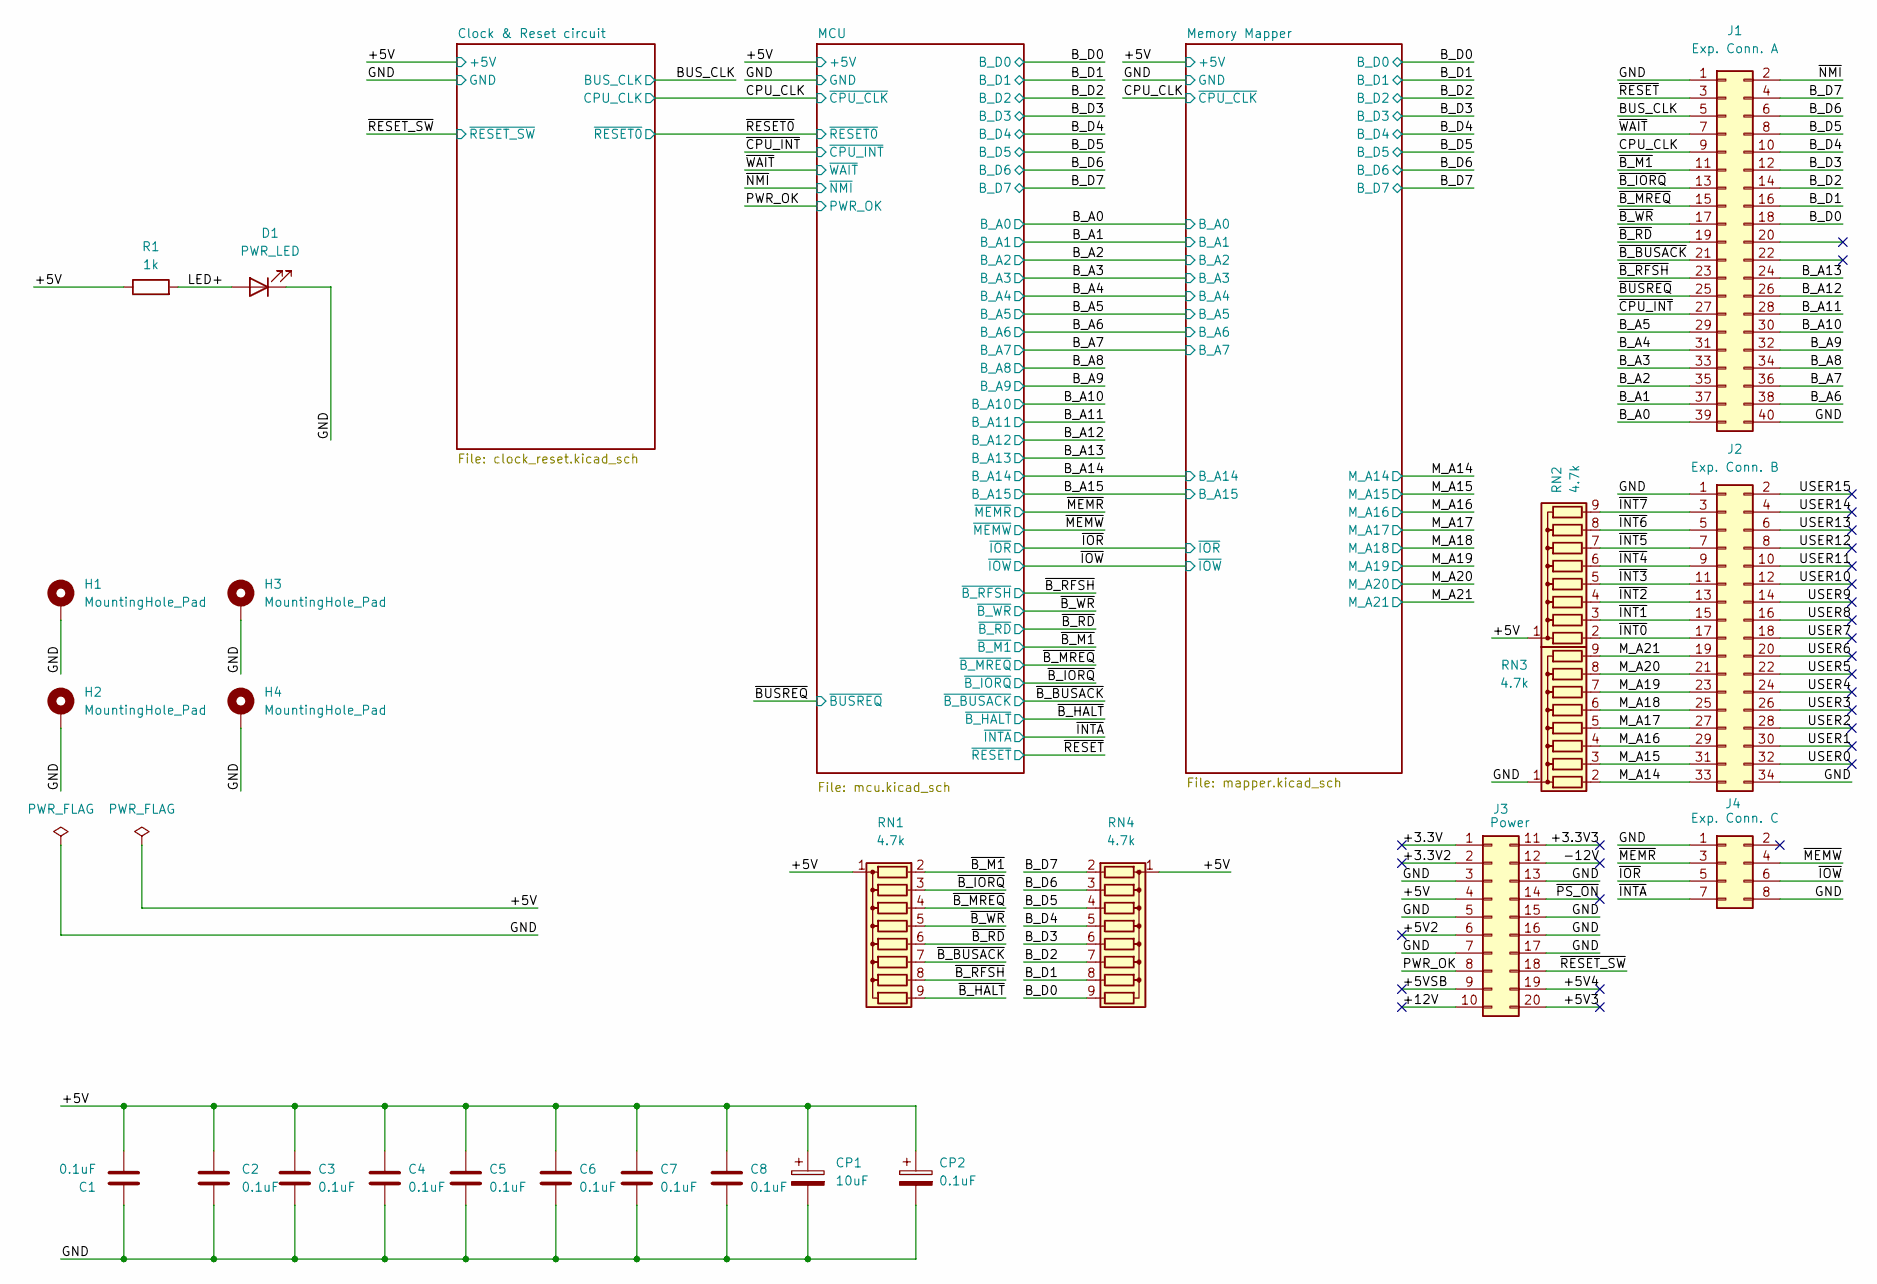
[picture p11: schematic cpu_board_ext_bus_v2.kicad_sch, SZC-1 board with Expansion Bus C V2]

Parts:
C1, C2, C3, C4, C5, C6, C7, C8: 0.1uF; C_Disc_D5.0mm_W2.5mm_P2.50mm; MPN FG28X7R1H104KNT06
CP1: 10uF; CP_Radial_D5.0mm_P2.50mm; MPN ECA1HM100I
CP2: 0.1uF; CP_Radial_D5.0mm_P2.50mm; MPN KS104M050C07RR0VH2FP0
D1: PWR_LED; LED_D3.0mm; MPN HLMP-1700
H1, H2, H3, H4: MountingHole_Pad; MountingHole_3.2mm_M3_ISO7380_Pad
J1: Exp. Conn. A; IDC-Header_2x20_P2.54mm_Horizontal; MPN X9555WR-2x20-6TV01
J2: Exp. Conn. B; IDC-Header_2x17_P2.54mm_Horizontal; MPN X9555WR-2x17-6TV01
J3: Power; IDC-Header_2x10_P2.54mm_Horizontal; MPN X9555WR-2x10-6TV01
J4: Exp. Conn. C; IDC-Header_2x04_P2.54mm_Horizontal; MPN 75867-132LF
R1: 1k; R_Axial_DIN0204_L3.6mm_D1.6mm_P7.62mm_Horizontal; MPN MBA02040C1001FC100
RN1, RN2, RN3, RN4: 4.7k; R_Array_SIP9; MPN A09-472JP

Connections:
/+3.3V: J3.1
/+3.3V2: J3.2
/+3.3V3: J3.11
/+5V: C1.1, C2.1, C3.1, C4.1, C5.1, C6.1, C7.1, C8.1, CP1.1, CP2.1, J3.4, R1.1, RN1.1 (common), RN2.1 (common), RN4.1 (common); also elsewhere on the board
/+5V2: J3.6
/+5V3: J3.20
/+5V4: J3.19
/+5VSB: J3.9
/+12V: J3.10
/-12V: J3.12
/BUS_CLK: J1.5; also elsewhere on the board
/B_A0: J1.39; also elsewhere on the board
/B_A1: J1.37; also elsewhere on the board
/B_A2: J1.35; also elsewhere on the board
/B_A3: J1.33; also elsewhere on the board
/B_A4: J1.31; also elsewhere on the board
/B_A5: J1.29; also elsewhere on the board
/B_A6: J1.38; also elsewhere on the board
/B_A7: J1.36; also elsewhere on the board
/B_A8: J1.34; also elsewhere on the board
/B_A9: J1.32; also elsewhere on the board
/B_A10: J1.30; also elsewhere on the board
/B_A11: J1.28; also elsewhere on the board
/B_A12: J1.26; also elsewhere on the board
/B_A13: J1.24; also elsewhere on the board
/B_D0: J1.18, RN4.9 (R8); also elsewhere on the board
/B_D1: J1.16, RN4.8 (R7); also elsewhere on the board
/B_D2: J1.14, RN4.7 (R6); also elsewhere on the board
/B_D3: J1.12, RN4.6 (R5); also elsewhere on the board
/B_D4: J1.10, RN4.5 (R4); also elsewhere on the board
/B_D5: J1.8, RN4.4 (R3); also elsewhere on the board
/B_D6: J1.6, RN4.3 (R2); also elsewhere on the board
/B_D7: J1.4, RN4.2 (R1); also elsewhere on the board
/CPU_CLK: J1.9; also elsewhere on the board
/GND: C1.2, C2.2, C3.2, C4.2, C5.2, C6.2, C7.2, C8.2, CP1.2, CP2.2, D1.1 (K), H1.1, H2.1, H3.1, H4.1, J1.1, J1.40, J2.1, J2.34, J3.3, J3.5, J3.7, J3.13, J3.15, J3.16, J3.17, J4.1, J4.8, RN3.1 (common); also elsewhere on the board
/LED+: D1.2 (A), R1.2
/M_A14: J2.33, RN3.2 (R1); also elsewhere on the board
/M_A15: J2.31, RN3.3 (R2); also elsewhere on the board
/M_A16: J2.29, RN3.4 (R3); also elsewhere on the board
/M_A17: J2.27, RN3.5 (R4); also elsewhere on the board
/M_A18: J2.25, RN3.6 (R5); also elsewhere on the board
/M_A19: J2.23, RN3.7 (R6); also elsewhere on the board
/M_A20: J2.21, RN3.8 (R7); also elsewhere on the board
/M_A21: J2.19, RN3.9 (R8); also elsewhere on the board
/PWR_OK: J3.8; also elsewhere on the board
/USER0: J2.32
/USER1: J2.30
/USER2: J2.28
/USER3: J2.26
/USER4: J2.24
/USER5: J2.22
/USER6: J2.20
/USER7: J2.18
/USER8: J2.16
/USER9: J2.14
/USER10: J2.12
/USER11: J2.10
/USER12: J2.8
/USER13: J2.6
/USER14: J2.4
/USER15: J2.2
/~BUSREQ: J1.25; also elsewhere on the board
/~B_BUSACK: J1.21, RN1.7 (R6); also elsewhere on the board
/~B_HALT: RN1.9 (R8); also elsewhere on the board
/~B_IORQ: J1.13, RN1.3 (R2); also elsewhere on the board
/~B_M1: J1.11, RN1.2 (R1); also elsewhere on the board
/~B_MREQ: J1.15, RN1.4 (R3); also elsewhere on the board
/~B_RD: J1.19, RN1.6 (R5); also elsewhere on the board
/~B_RFSH: J1.23, RN1.8 (R7); also elsewhere on the board
/~B_WR: J1.17, RN1.5 (R4); also elsewhere on the board
/~CPU_INT: J1.27; also elsewhere on the board
/~INT0: J2.17, RN2.2 (R1)
/~INT1: J2.15, RN2.3 (R2)
/~INT2: J2.13, RN2.4 (R3)
/~INT3: J2.11, RN2.5 (R4)
/~INT4: J2.9, RN2.6 (R5)
/~INT5: J2.7, RN2.7 (R6)
/~INT6: J2.5, RN2.8 (R7)
/~INT7: J2.3, RN2.9 (R8)
/~INTA: J4.7; also elsewhere on the board
/~IOR: J4.5; also elsewhere on the board
/~IOW: J4.6; also elsewhere on the board
/~MEMR: J4.3; also elsewhere on the board
/~MEMW: J4.4; also elsewhere on the board
/~NMI: J1.2; also elsewhere on the board
/~PS_ON: J3.14
/~RESET_SW: J3.18; also elsewhere on the board
/~RESET: J1.3; also elsewhere on the board
/~WAIT: J1.7; also elsewhere on the board

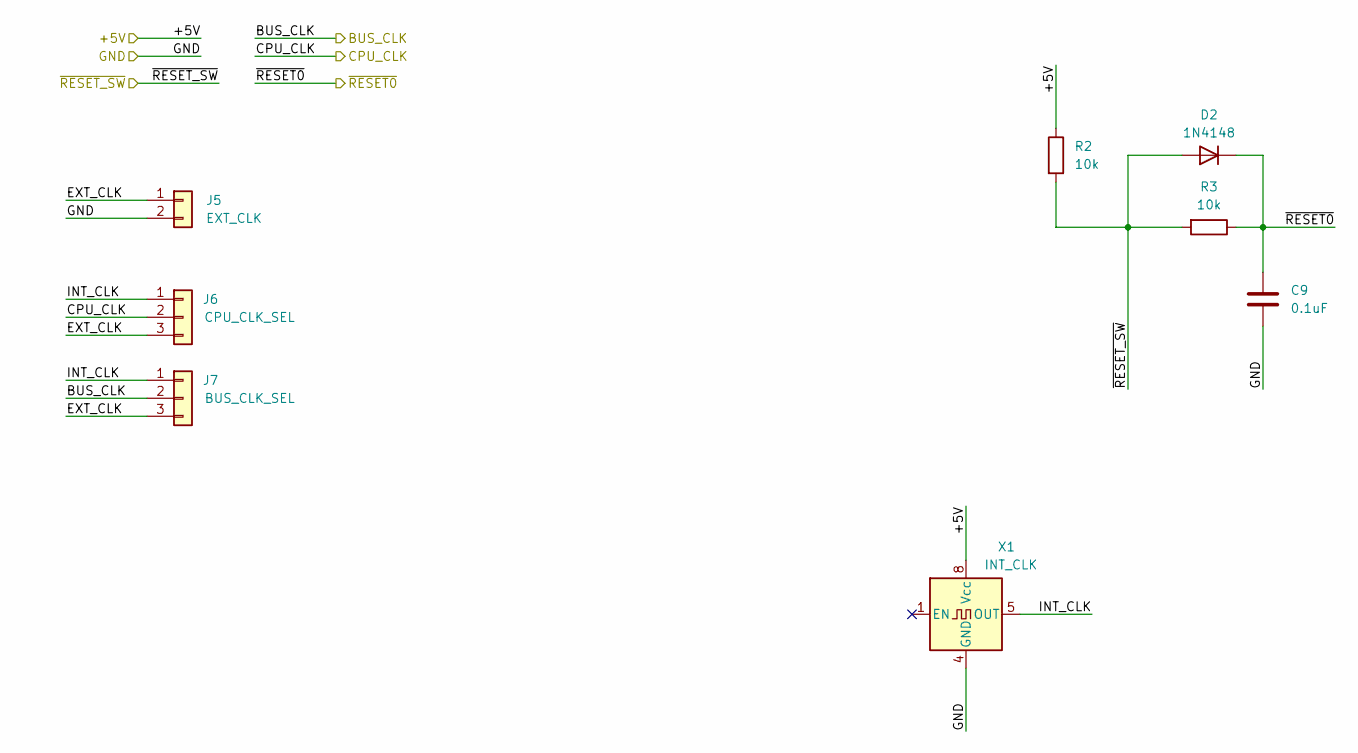
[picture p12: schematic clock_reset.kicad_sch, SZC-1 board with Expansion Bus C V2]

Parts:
C9: 0.1uF; C_Disc_D5.0mm_W2.5mm_P2.50mm; MPN FG28X7R1H104KNT06
D2: 1N4148; D_DO-35_SOD27_P7.62mm_Horizontal; MPN 1N4148TA
J5: EXT_CLK; PinHeader_1x02_P2.54mm_Horizontal; MPN PZ254R-11-02P
J6: CPU_CLK_SEL; PinHeader_1x03_P2.54mm_Horizontal; MPN PZ254R-11-03P
J7: BUS_CLK_SEL; PinHeader_1x03_P2.54mm_Horizontal; MPN PZ254R-11-03P
R2, R3: 10k; R_Axial_DIN0204_L3.6mm_D1.6mm_P7.62mm_Horizontal; MPN MBA02040C1002FRP00
X1: INT_CLK; Oscillator_DIP-8; MPN 1-2199298-2

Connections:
/+5V: R2.1, X1.8 (Vcc); also elsewhere on the board
/BUS_CLK: J7.2; also elsewhere on the board
/CPU_CLK: J6.2; also elsewhere on the board
/Clock & Reset circuit/EXT_CLK: J5.1, J6.3, J7.3
/Clock & Reset circuit/INT_CLK: J6.1, J7.1, X1.5 (OUT)
/GND: C9.2, J5.2, X1.4 (GND); also elsewhere on the board
/~RESET0: C9.1, D2.1 (K), R3.1; also elsewhere on the board
/~RESET_SW: D2.2 (A), R2.2, R3.2; also elsewhere on the board

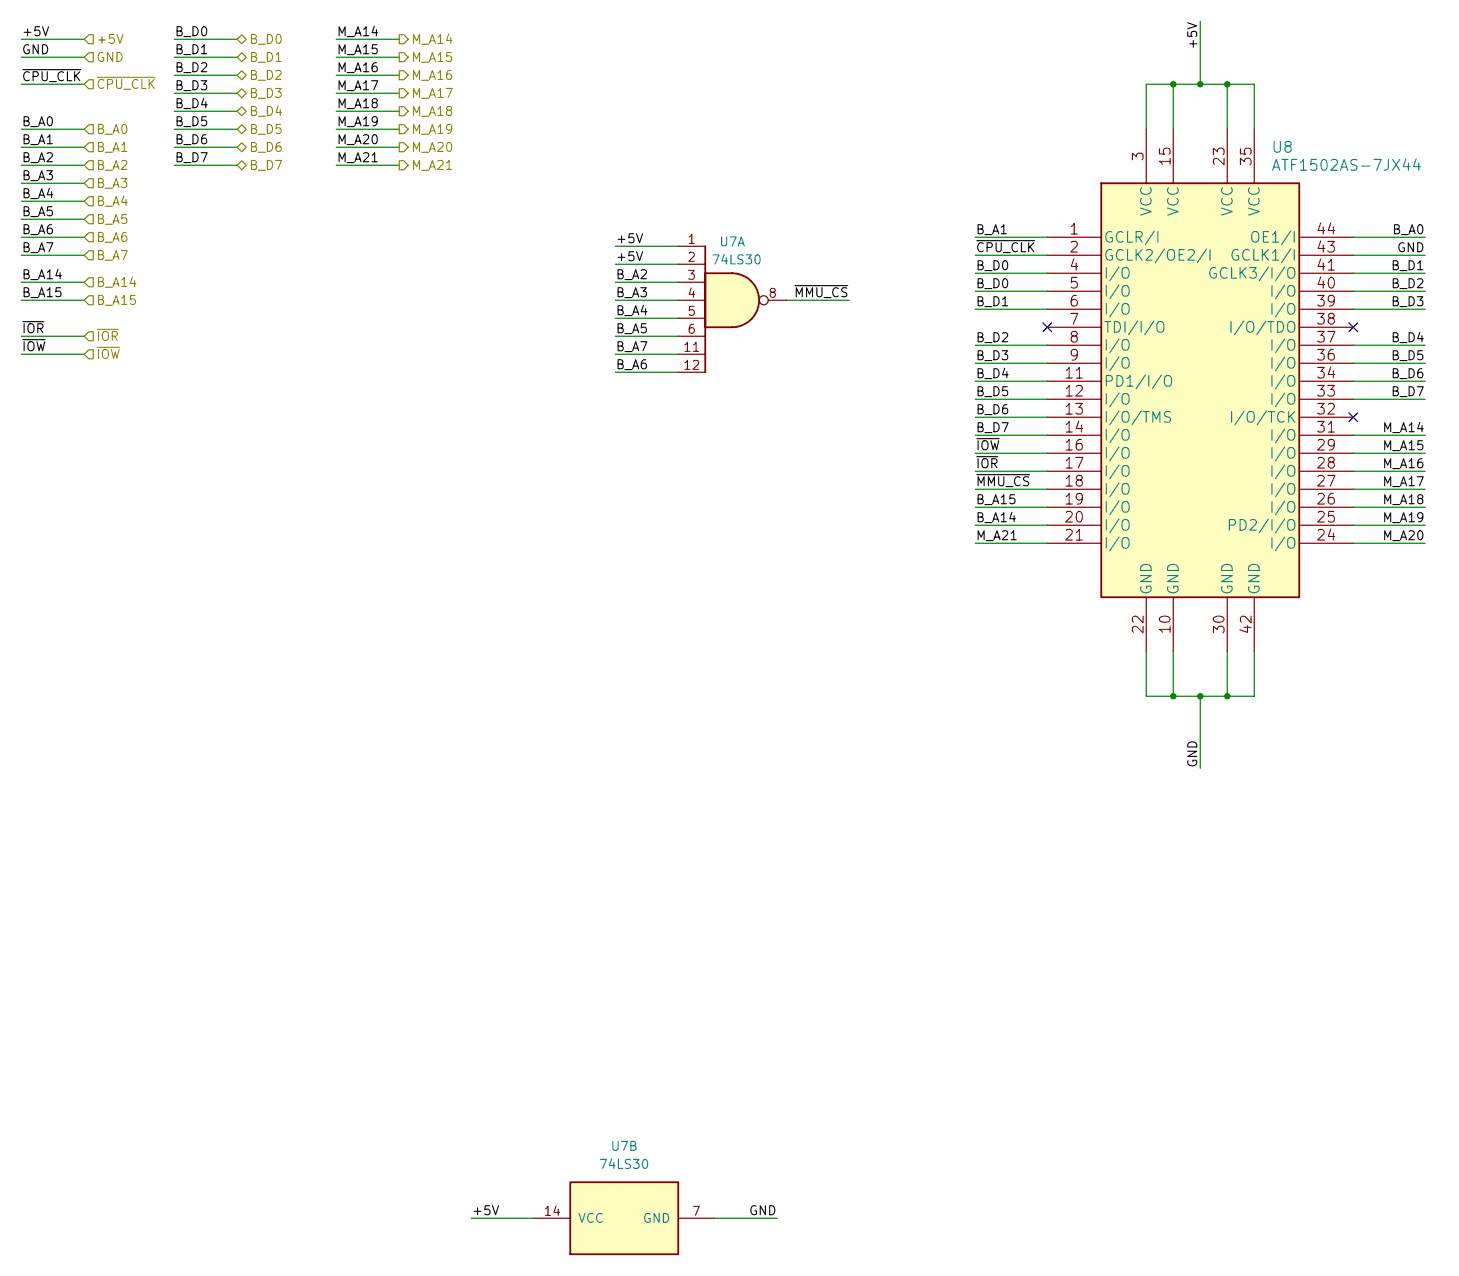
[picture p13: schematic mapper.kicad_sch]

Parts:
U7: 74LS30; DIP-14_W7.62mm_Socket; MPN 1-2199298-3
U8: ATF1502AS-7JX44; PLCC-44_THT-Socket; MPN DS1032-44SDKT1A

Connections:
/+5V: U7.1, U7.2, U7.14 (VCC), U8.3 (VCC), U8.15 (VCC), U8.23 (VCC), U8.35 (VCC); also elsewhere on the board
/B_A0: U8.44 (OE1/I); also elsewhere on the board
/B_A1: U8.1 (GCLR/I); also elsewhere on the board
/B_A2: U7.3; also elsewhere on the board
/B_A3: U7.4; also elsewhere on the board
/B_A4: U7.5; also elsewhere on the board
/B_A5: U7.6; also elsewhere on the board
/B_A6: U7.12; also elsewhere on the board
/B_A7: U7.11; also elsewhere on the board
/B_A14: U8.20 (I/O); also elsewhere on the board
/B_A15: U8.19 (I/O); also elsewhere on the board
/B_D0: U8.4 (I/O), U8.5 (I/O); also elsewhere on the board
/B_D1: U8.6 (I/O), U8.41 (GCLK3/I/O); also elsewhere on the board
/B_D2: U8.8 (I/O), U8.40 (I/O); also elsewhere on the board
/B_D3: U8.9 (I/O), U8.39 (I/O); also elsewhere on the board
/B_D4: U8.11 (PD1/I/O), U8.37 (I/O); also elsewhere on the board
/B_D5: U8.12 (I/O), U8.36 (I/O); also elsewhere on the board
/B_D6: U8.13 (I/O/TMS), U8.34 (I/O); also elsewhere on the board
/B_D7: U8.14 (I/O), U8.33 (I/O); also elsewhere on the board
/CPU_CLK: U8.2 (GCLK2/OE2/I); also elsewhere on the board
/GND: U7.7 (GND), U8.10 (GND), U8.22 (GND), U8.30 (GND), U8.42 (GND), U8.43 (GCLK1/I); also elsewhere on the board
/M_A14: U8.31 (I/O); also elsewhere on the board
/M_A15: U8.29 (I/O); also elsewhere on the board
/M_A16: U8.28 (I/O); also elsewhere on the board
/M_A17: U8.27 (I/O); also elsewhere on the board
/M_A18: U8.26 (I/O); also elsewhere on the board
/M_A19: U8.25 (PD2/I/O); also elsewhere on the board
/M_A20: U8.24 (I/O); also elsewhere on the board
/M_A21: U8.21 (I/O); also elsewhere on the board
/Memory Mapper/~MMU_CS: U7.8, U8.18 (I/O)
/~IOR: U8.17 (I/O); also elsewhere on the board
/~IOW: U8.16 (I/O); also elsewhere on the board

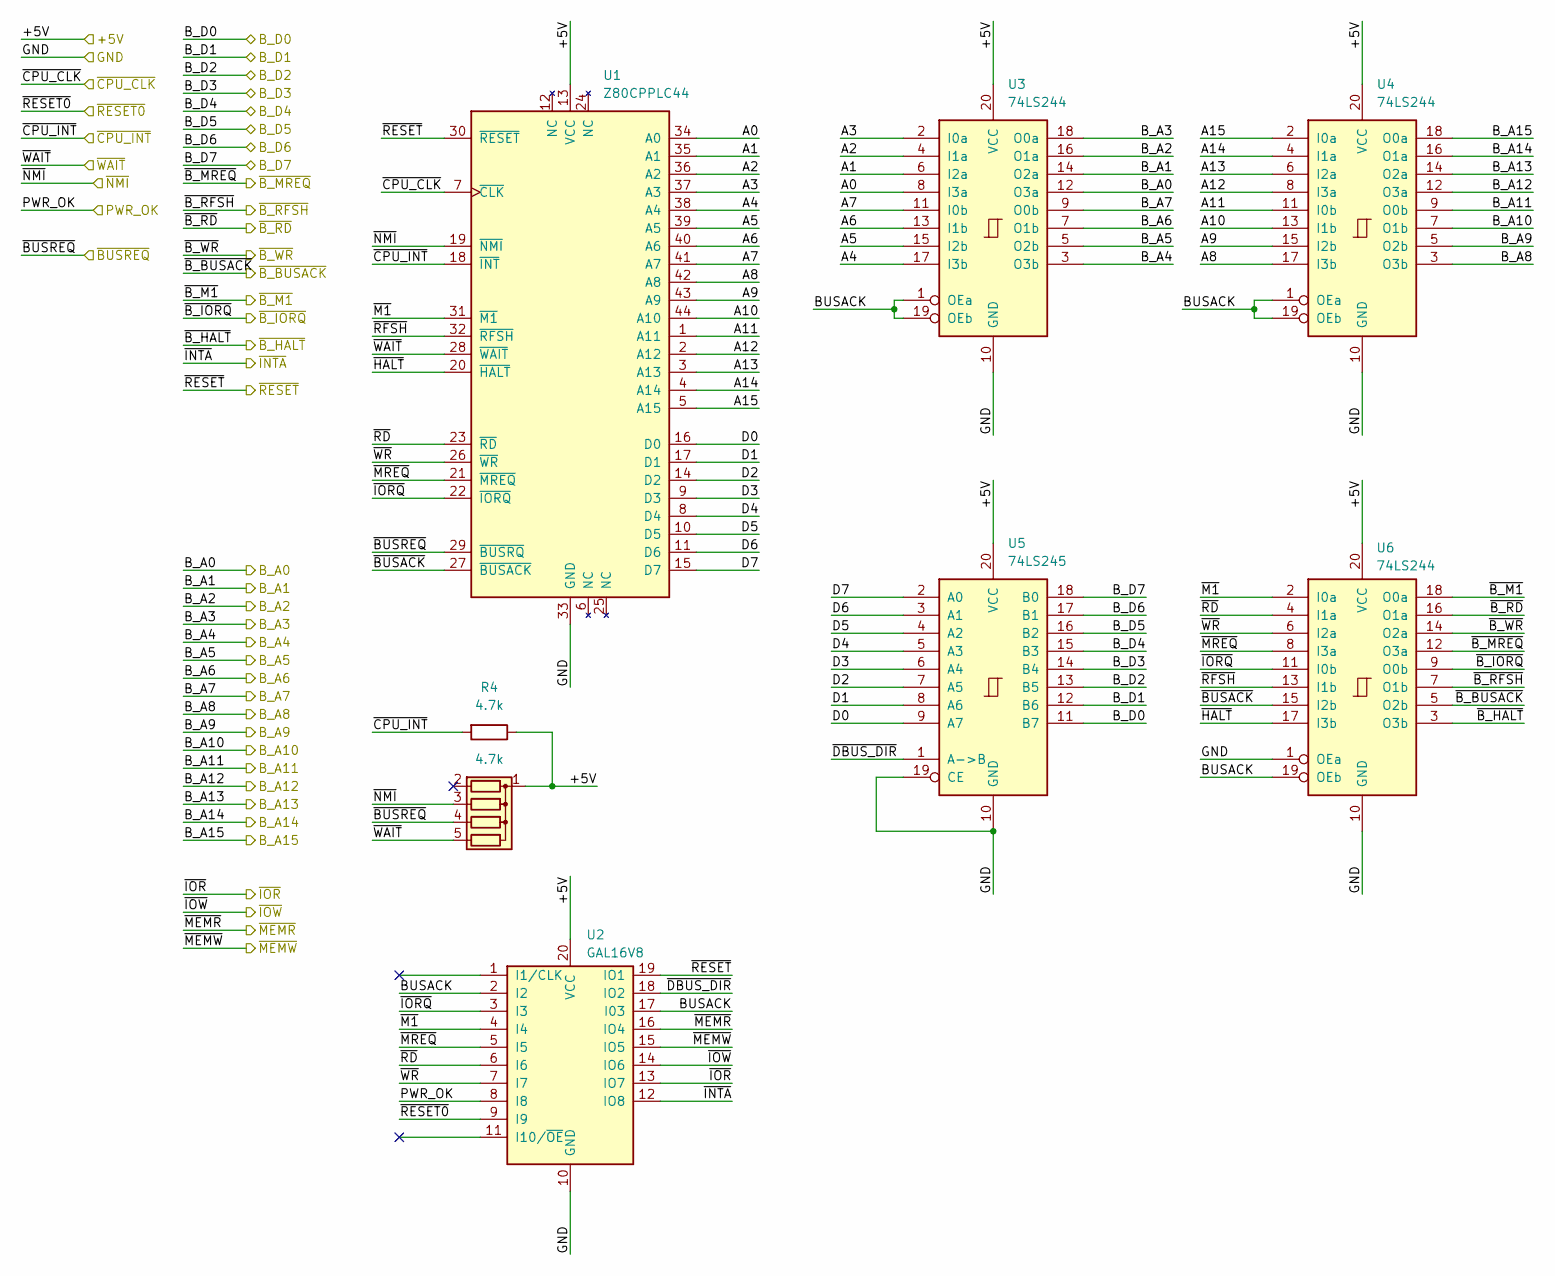
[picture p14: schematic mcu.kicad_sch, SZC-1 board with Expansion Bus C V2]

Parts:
R4: 4.7k; R_Axial_DIN0204_L3.6mm_D1.6mm_P7.62mm_Horizontal; MPN MF0207FTE52-4K7
RN5: 4.7k; R_Array_SIP5; MPN A05-472JP
U1: Z80CPPLC44; PLCC-44_THT-Socket; MPN DS1032-44SDKT1A
U2: GAL16V8; DIP-20_W7.62mm_Socket; MPN 1-2199298-6
U3, U4, U6: 74LS244; DIP-20_W7.62mm_Socket; MPN 1-2199298-6
U5: 74LS245; DIP-20_W7.62mm_Socket; MPN 1-2199298-6

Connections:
/+5V: R4.1, RN5.1 (common), U1.13 (VCC), U2.20 (VCC), U3.20 (VCC), U4.20 (VCC), U5.20 (VCC), U6.20 (VCC); also elsewhere on the board
/B_A0: U3.12 (O3a); also elsewhere on the board
/B_A1: U3.14 (O2a); also elsewhere on the board
/B_A2: U3.16 (O1a); also elsewhere on the board
/B_A3: U3.18 (O0a); also elsewhere on the board
/B_A4: U3.3 (O3b); also elsewhere on the board
/B_A5: U3.5 (O2b); also elsewhere on the board
/B_A6: U3.7 (O1b); also elsewhere on the board
/B_A7: U3.9 (O0b); also elsewhere on the board
/B_A8: U4.3 (O3b); also elsewhere on the board
/B_A9: U4.5 (O2b); also elsewhere on the board
/B_A10: U4.7 (O1b); also elsewhere on the board
/B_A11: U4.9 (O0b); also elsewhere on the board
/B_A12: U4.12 (O3a); also elsewhere on the board
/B_A13: U4.14 (O2a); also elsewhere on the board
/B_A14: U4.16 (O1a); also elsewhere on the board
/B_A15: U4.18 (O0a); also elsewhere on the board
/B_D0: U5.11 (B7); also elsewhere on the board
/B_D1: U5.12 (B6); also elsewhere on the board
/B_D2: U5.13 (B5); also elsewhere on the board
/B_D3: U5.14 (B4); also elsewhere on the board
/B_D4: U5.15 (B3); also elsewhere on the board
/B_D5: U5.16 (B2); also elsewhere on the board
/B_D6: U5.17 (B1); also elsewhere on the board
/B_D7: U5.18 (B0); also elsewhere on the board
/CPU_CLK: U1.7 (~CLK); also elsewhere on the board
/GND: U1.33 (GND), U2.10 (GND), U3.10 (GND), U4.10 (GND), U5.10 (GND), U5.19 (CE), U6.1 (OEa), U6.10 (GND); also elsewhere on the board
/MCU/A0: U1.34 (A0), U3.8 (I3a)
/MCU/A1: U1.35 (A1), U3.6 (I2a)
/MCU/A2: U1.36 (A2), U3.4 (I1a)
/MCU/A3: U1.37 (A3), U3.2 (I0a)
/MCU/A4: U1.38 (A4), U3.17 (I3b)
/MCU/A5: U1.39 (A5), U3.15 (I2b)
/MCU/A6: U1.40 (A6), U3.13 (I1b)
/MCU/A7: U1.41 (A7), U3.11 (I0b)
/MCU/A8: U1.42 (A8), U4.17 (I3b)
/MCU/A9: U1.43 (A9), U4.15 (I2b)
/MCU/A10: U1.44 (A10), U4.13 (I1b)
/MCU/A11: U1.1 (A11), U4.11 (I0b)
/MCU/A12: U1.2 (A12), U4.8 (I3a)
/MCU/A13: U1.3 (A13), U4.6 (I2a)
/MCU/A14: U1.4 (A14), U4.4 (I1a)
/MCU/A15: U1.5 (A15), U4.2 (I0a)
/MCU/BUSACK: U2.2 (I2), U2.17 (I03), U3.1 (OEa), U3.19 (OEb), U4.1 (OEa), U4.19 (OEb), U6.19 (OEb)
/MCU/D0: U1.16 (D0), U5.9 (A7)
/MCU/D1: U1.17 (D1), U5.8 (A6)
/MCU/D2: U1.14 (D2), U5.7 (A5)
/MCU/D3: U1.9 (D3), U5.6 (A4)
/MCU/D4: U1.8 (D4), U5.5 (A3)
/MCU/D5: U1.10 (D5), U5.4 (A2)
/MCU/D6: U1.11 (D6), U5.3 (A1)
/MCU/D7: U1.15 (D7), U5.2 (A0)
/MCU/~BUSACK: U1.27 (~BUSACK), U6.15 (I2b)
/MCU/~DBUS_DIR: U2.18 (IO2), U5.1 (A->B)
/MCU/~HALT: U1.20 (~HALT), U6.17 (I3b)
/MCU/~IORQ: U1.22 (~IORQ), U2.3 (I3), U6.11 (I0b)
/MCU/~M1: U1.31 (~M1), U2.4 (I4), U6.2 (I0a)
/MCU/~MREQ: U1.21 (~MREQ), U2.5 (I5), U6.8 (I3a)
/MCU/~RD: U1.23 (~RD), U2.6 (I6), U6.4 (I1a)
/MCU/~RFSH: U1.32 (~RFSH), U6.13 (I1b)
/MCU/~WR: U1.26 (~WR), U2.7 (I7), U6.6 (I2a)
/PWR_OK: U2.8 (I8); also elsewhere on the board
/~BUSREQ: RN5.4 (R3), U1.29 (~BUSRQ); also elsewhere on the board
/~B_BUSACK: U6.5 (O2b); also elsewhere on the board
/~B_HALT: U6.3 (O3b); also elsewhere on the board
/~B_IORQ: U6.9 (O0b); also elsewhere on the board
/~B_M1: U6.18 (O0a); also elsewhere on the board
/~B_MREQ: U6.12 (O3a); also elsewhere on the board
/~B_RD: U6.16 (O1a); also elsewhere on the board
/~B_RFSH: U6.7 (O1b); also elsewhere on the board
/~B_WR: U6.14 (O2a); also elsewhere on the board
/~CPU_INT: R4.2, U1.18 (~INT); also elsewhere on the board
/~INTA: U2.12 (IO8); also elsewhere on the board
/~IOR: U2.13 (IO7); also elsewhere on the board
/~IOW: U2.14 (IO6); also elsewhere on the board
/~MEMR: U2.16 (IO4); also elsewhere on the board
/~MEMW: U2.15 (IO5); also elsewhere on the board
/~NMI: RN5.3 (R2), U1.19 (~NMI); also elsewhere on the board
/~RESET0: U2.9 (I9); also elsewhere on the board
/~RESET: U1.30 (~RESET), U2.19 (IO1); also elsewhere on the board
/~WAIT: RN5.5 (R4), U1.28 (~WAIT); also elsewhere on the board

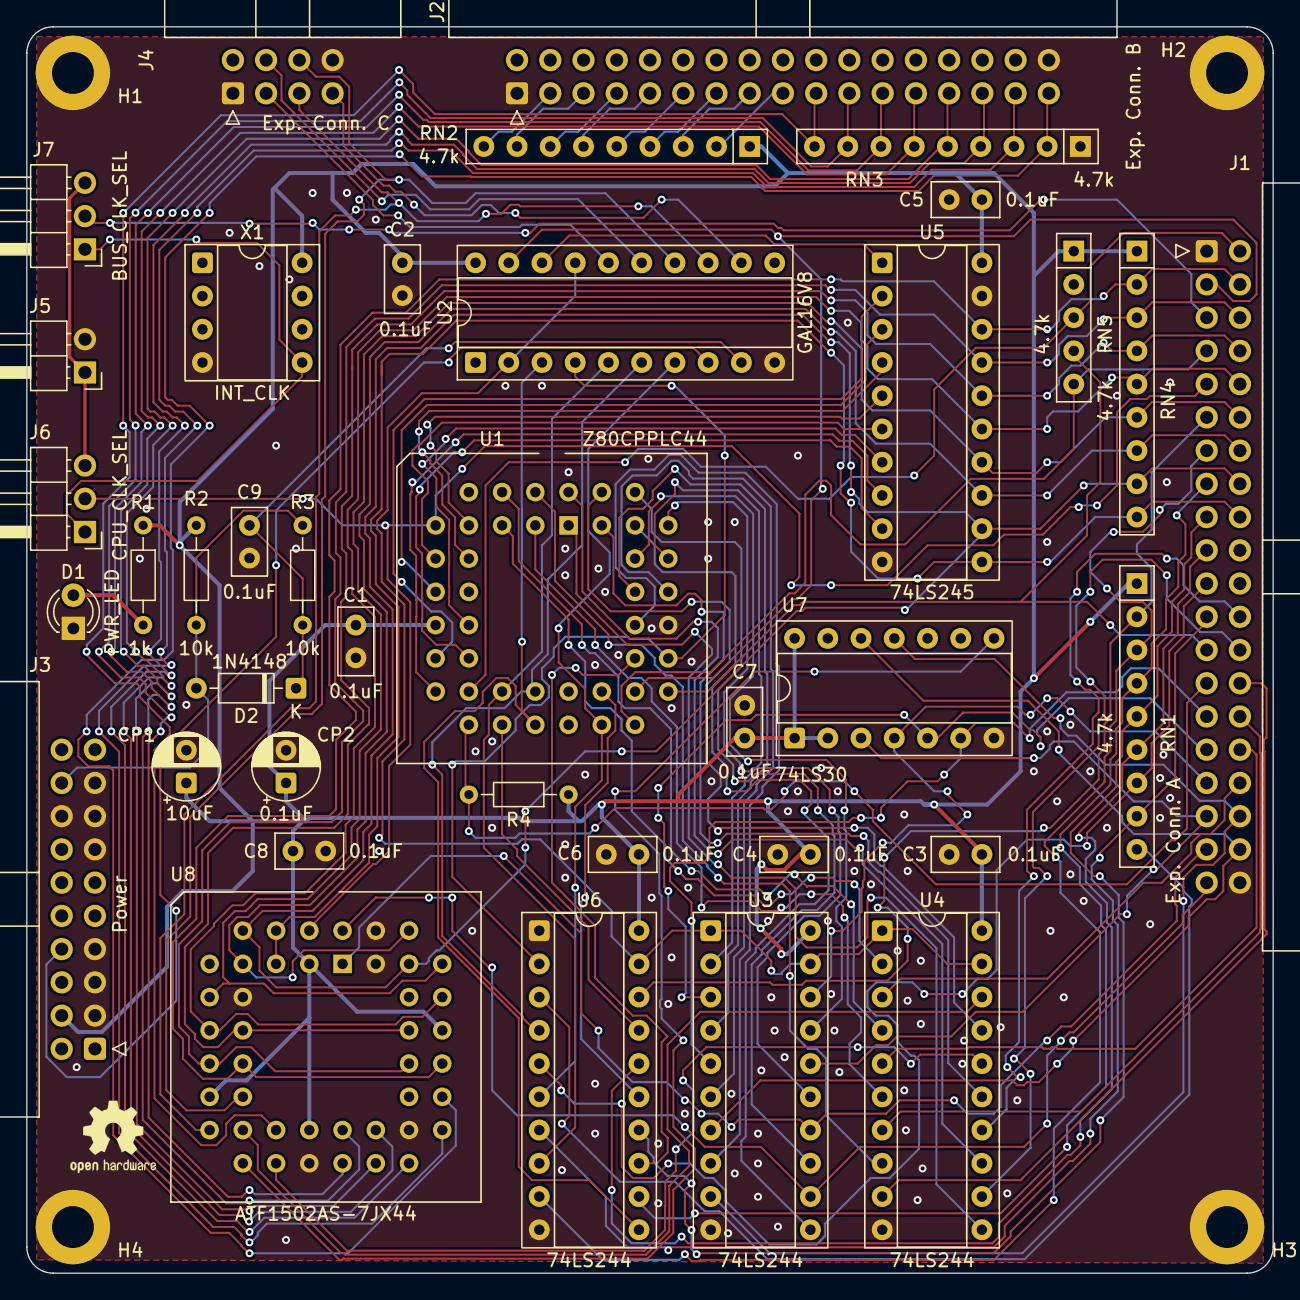
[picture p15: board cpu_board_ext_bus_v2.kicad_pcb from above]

Board: 2 copper layers, 95.2 x 95.2 mm, 42 parts (0 on the bottom side), 103 nets.

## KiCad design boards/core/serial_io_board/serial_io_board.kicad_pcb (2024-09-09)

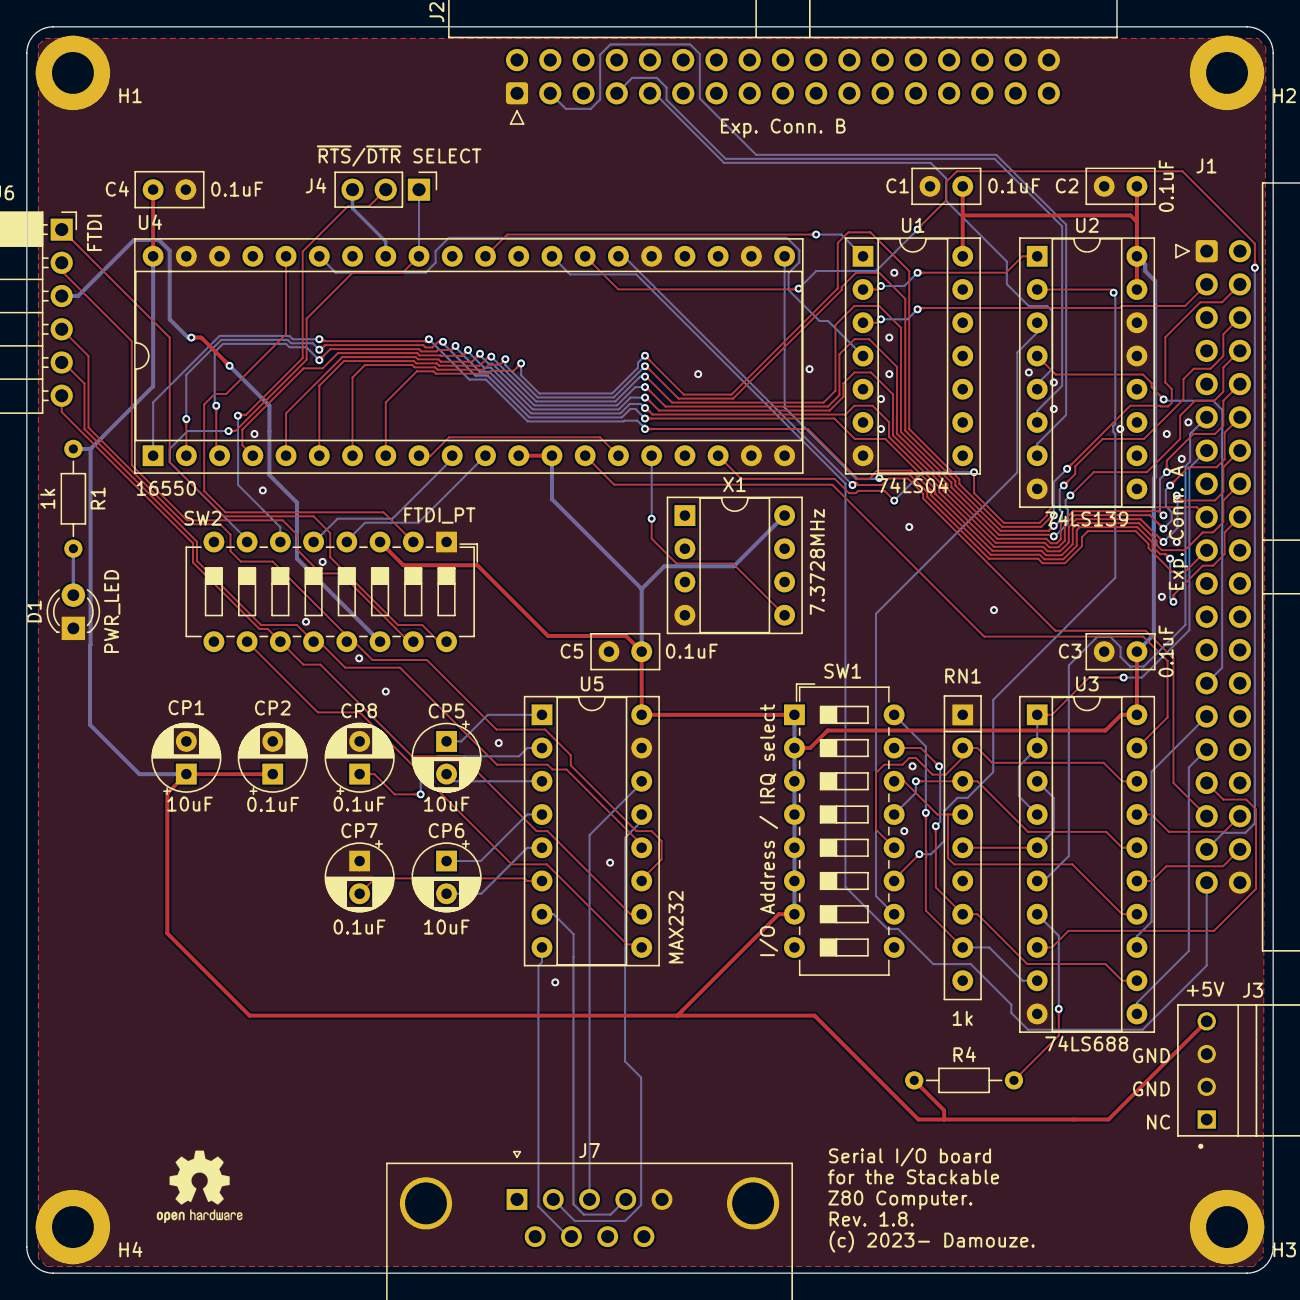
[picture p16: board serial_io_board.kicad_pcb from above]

Board: 2 copper layers, 95.2 x 95.2 mm, 33 parts (0 on the bottom side), 66 nets.

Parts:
C1, C2, C3, C4, C5: 0.1uF; C_Disc_D5.0mm_W2.5mm_P2.50mm
CP1, CP5, CP6: 10uF; CP_Radial_D5.0mm_P2.50mm
CP2, CP7, CP8: 0.1uF; CP_Radial_D5.0mm_P2.50mm
D1: PWR_LED; LED_D3.0mm
H1, H2, H3, H4: MountingHole_Pad; MountingHole_3.2mm_M3_ISO7380_Pad
J1: Exp. Conn. A; IDC-Header_2x20_P2.54mm_Horizontal
J2: Exp. Conn. B; IDC-Header_2x17_P2.54mm_Horizontal
J3: Power; TE_171826-4
J4: ~{RTS}/~{DTR} SELECT; PinHeader_1x03_P2.54mm_Vertical
J6: FTDI; PinSocket_1x06_P2.54mm_Horizontal
J7: COM1; DSUB-9_Male_Horizontal_P2.77x2.84mm_EdgePinOffset4.94mm_Hou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
R1: 1k; R_Axial_DIN0204_L3.6mm_D1.6mm_P7.62mm_Horizontal
R4: 4.7k; R_Axial_DIN0204_L3.6mm_D1.6mm_P7.62mm_Horizontal
RN1: 1k; R_Array_SIP9
SW1: I/O Address / IRQ select; SW_DIP_SPSTx08_Slide_6.7x21.88mm_W7.62mm_P2.54mm_LowProfile
SW2: FTDI_PT; SW_DIP_SPSTx08_Slide_6.7x21.88mm_W7.62mm_P2.54mm_LowProfile
U1: 74LS04; DIP-14_W7.62mm_Socket
U2: 74LS139; DIP-16_W7.62mm_Socket
U3: 74LS688; DIP-20_W7.62mm_Socket
U4: 16550; DIP-40_W15.24mm_Socket
U5: MAX232; DIP-16_W7.62mm_Socket
X1: 7.3728MHz; DIP-8_W7.62mm_Socket

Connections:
/+5V: C1.1, C2.1, C3.1, C4.1, C5.1, CP1.1, CP2.1, J3.4, R1.1, R4.1, SW1.1, SW1.2, SW1.3, SW1.4, SW1.5, SW1.6, SW1.7, SW2.3, U1.14 (VCC), U2.15 (E), U2.16 (VCC), U3.20 (VCC), U4.12 (CS0), U4.13 (CS1), U4.40 (VCC), U5.16 (VCC), X1.8 (Vcc)
/B_A0: J1.39, U4.28 (A0)
/B_A1: J1.37, U4.27 (A1)
/B_A2: J1.35, U4.26 (A2)
/B_A3: J1.33, U3.8 (P3)
/B_A4: J1.31, U3.11 (P4)
/B_A5: J1.29, U3.13 (P5)
/B_A6: J1.38, U3.15 (P6)
/B_A7: J1.36, U3.17 (P7)
/B_D0: J1.18, U4.1 (D0)
/B_D1: J1.16, U4.2 (D1)
/B_D2: J1.14, U4.3 (D2)
/B_D3: J1.12, U4.4 (D3)
/B_D4: J1.10, U4.5 (D4)
/B_D5: J1.8, U4.6 (D5)
/B_D6: J1.6, U4.7 (D6)
/B_D7: J1.4, U4.8 (D7)
/FTDI_VCC: J6.3, SW2.14
/GND: C1.2, C2.2, C3.2, C4.2, C5.2, CP1.2, CP2.2, CP7.1, CP8.2, D1.1 (K), H1.1, H2.1, H3.1, H4.1, J1.1, J1.40, J2.1, J2.34, J3.2, J3.3, J7.0 (PAD), J7.5, RN1.1 (common), SW2.1, U1.7 (GND), U2.8 (GND), U2.13 (A1), U2.14 (A0), U3.10 (GND), U4.19 (WR), U4.20 (GND), U4.22 (RD), U4.25 (~ADS), U4.38 (~DCD), U4.39 (~RI), U5.15 (GND), X1.4 (GND)
/IRQ0_S: SW1.11, U2.2 (A0)
/IRQ1_S: SW1.10, U2.3 (A1)
/RX: J6.5, SW2.12, U5.12 (R1OUT)
/R_A3: RN1.8 (R7), SW1.16, U3.9 (R3)
/R_A4: RN1.7 (R6), SW1.15, U3.12 (R4)
/R_A5: RN1.4 (R3), SW1.14, U3.14 (R5)
/R_A6: RN1.3 (R2), SW1.13, U3.16 (R6)
/R_A7: RN1.2 (R1), SW1.12, U3.18 (R7)
/S_DTR: J7.4, U5.7 (T2OUT)
/S_RTS: J7.7, U5.8 (R2IN)
/S_RX: J7.2, U5.13 (R1IN)
/S_TX: J7.3, U5.14 (T1OUT)
/TX: J6.4, SW2.13, U5.11 (T1IN)
/UART_CLK: U4.16 (XIN), X1.5 (OUT)
/UART_INT: U1.1, U4.30 (INTR)
/UART_RESET: U1.4, U4.35 (MR)
/UART_SIN: SW2.5, U4.10 (SIN)
/UART_SOUT: SW2.4, U4.11 (SOUT)
/~BAUDOUT: U4.9 (RCLK), U4.15 (~BAUDOUT)
/~B_IORQ: J1.13, U3.1 (G), U3.2 (P0), U3.4 (P1)
/~B_M1: J1.11, U3.6 (P2)
/~B_RD: J1.19, U4.21 (~RD)
/~B_WR: J1.17, U4.18 (~WR)
/~CTS: J6.2, SW2.15
/~DTR: J6.6, SW2.11, U5.10 (T2IN)
/~FTDI_DTR: J4.2, SW2.6
/~INT4: J2.9, U2.5 (O1)
/~INT5: J2.7, U2.6 (O2)
/~INT7: J2.3, U2.7 (O3)
/~INT: J1.27, U2.4 (O0)
/~RESET: J1.3, U1.3
/~RTS: SW2.10, U5.9 (R2OUT)
/~R_IORQ: RN1.5 (R4), U3.3 (R0), U3.5 (R1)
/~R_M1: R4.2, U3.7 (R2)
/~UART_CS: U3.19 (P=R), U4.14 (~CS2)
/~UART_CTS: SW2.2, U4.36 (~CTS)
/~UART_DTR: J4.3, U4.33 (~DTR)
/~UART_INT: U1.2, U2.1 (E)
/~UART_RTS: J4.1, SW2.7, U4.32 (~RTS)
unnamed: D1.2 (A), R1.2
unnamed: J6.1, SW2.16
unnamed: CP5.1, U5.1 (C1+)
unnamed: CP5.2, U5.3 (C1-)
unnamed: CP6.1, U5.4 (C2+)
unnamed: CP6.2, U5.5 (C2-)
unnamed: CP8.1, U5.2 (VS+)
unnamed: CP7.2, U5.6 (VS-)

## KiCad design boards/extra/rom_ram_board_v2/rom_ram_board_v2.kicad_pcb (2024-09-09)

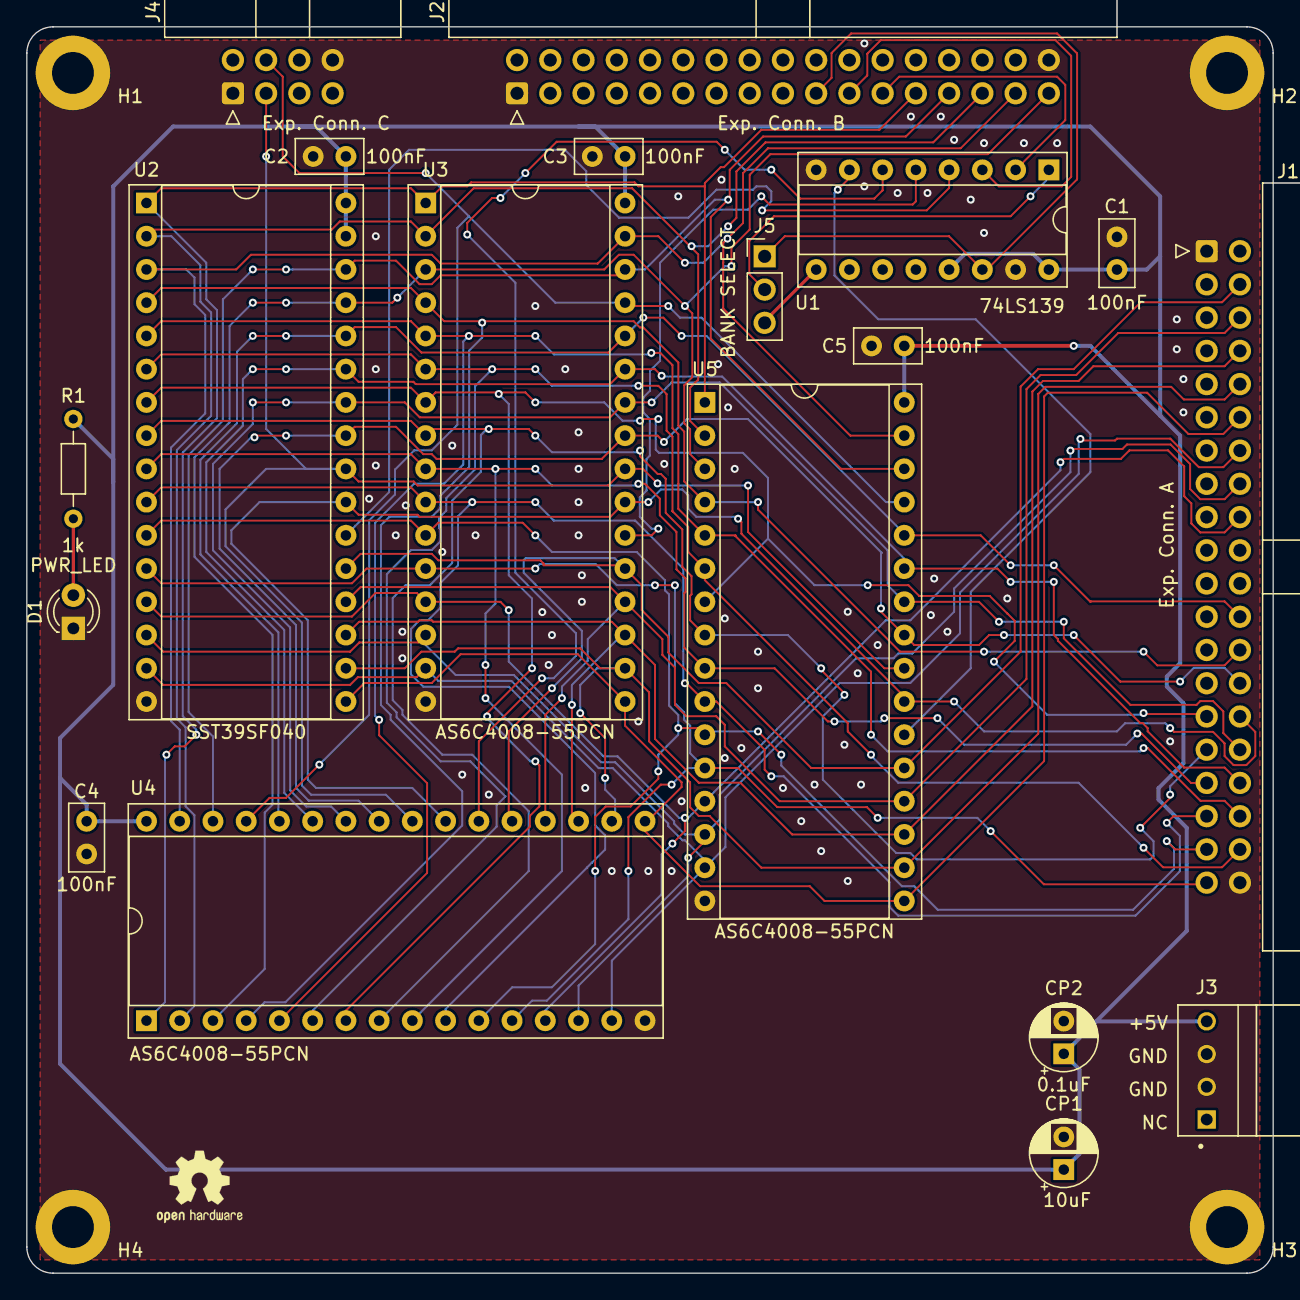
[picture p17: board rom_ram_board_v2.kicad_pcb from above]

Board: 2 copper layers, 95.2 x 95.2 mm, 23 parts (0 on the bottom side), 41 nets.

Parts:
C1, C2, C3, C4, C5: 100nF; C_Disc_D5.0mm_W2.5mm_P2.50mm
CP1: 10uF; CP_Radial_D5.0mm_P2.50mm
CP2: 0.1uF; CP_Radial_D5.0mm_P2.50mm
D1: PWR_LED; LED_D3.0mm
H1, H2, H3, H4: MountingHole_Pad; MountingHole_3.2mm_M3_ISO7380_Pad
J1: Exp. Conn. A; IDC-Header_2x20_P2.54mm_Horizontal
J2: Exp. Conn. B; IDC-Header_2x17_P2.54mm_Horizontal
J3: Power; TE_171826-4
J4: Exp. Conn. C; IDC-Header_2x04_P2.54mm_Horizontal
J5: BANK SELECT; PinHeader_1x03_P2.54mm_Vertical
R1: 1k; R_Axial_DIN0204_L3.6mm_D1.6mm_P7.62mm_Horizontal
U1: 74LS139; DIP-16_W7.62mm_Socket
U2: SST39SF040; DIP-32_W15.24mm_Socket
U3, U4, U5: AS6C4008-55PCN; DIP-32_W15.24mm_Socket

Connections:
/+5V: C1.1, C2.1, C3.1, C4.1, C5.1, CP1.1, CP2.1, J3.4, R1.1, U1.13 (A1), U1.16 (VCC), U2.31 (PGM), U2.32 (VCC), U3.32 (VCC), U4.32 (VCC), U5.32 (VCC)
/B_A0: J1.39, U2.12 (A0), U3.12 (A0), U4.12 (A0), U5.12 (A0)
/B_A1: J1.37, U2.11 (A1), U3.11 (A1), U4.11 (A1), U5.11 (A1)
/B_A2: J1.35, U2.10 (A2), U3.10 (A2), U4.10 (A2), U5.10 (A2)
/B_A3: J1.33, U2.9 (A3), U3.9 (A3), U4.9 (A3), U5.9 (A3)
/B_A4: J1.31, U2.8 (A4), U3.8 (A4), U4.8 (A4), U5.8 (A4)
/B_A5: J1.29, U2.7 (A5), U3.7 (A5), U4.7 (A5), U5.7 (A5)
/B_A6: J1.38, U2.6 (A6), U3.6 (A6), U4.6 (A6), U5.6 (A6)
/B_A7: J1.36, U2.5 (A7), U3.5 (A7), U4.5 (A7), U5.5 (A7)
/B_A8: J1.34, U2.27 (A8), U3.27 (A8), U4.27 (A8), U5.27 (A8)
/B_A9: J1.32, U2.26 (A9), U3.26 (A9), U4.26 (A9), U5.26 (A9)
/B_A10: J1.30, U2.23 (A10), U3.23 (A10), U4.23 (A10), U5.23 (A10)
/B_A11: J1.28, U2.25 (A11), U3.25 (A11), U4.25 (A11), U5.25 (A11)
/B_A12: J1.26, U2.4 (A12), U3.4 (A12), U4.4 (A12), U5.4 (A12)
/B_A13: J1.24, U2.28 (A13), U3.28 (A13), U4.28 (A13), U5.28 (A13)
/B_D0: J1.18, U2.13 (D0), U3.13 (DQ0), U4.13 (DQ0), U5.13 (DQ0)
/B_D1: J1.16, U2.14 (D1), U3.14 (DQ1), U4.14 (DQ1), U5.14 (DQ1)
/B_D2: J1.14, U2.15 (D2), U3.15 (DQ2), U4.15 (DQ2), U5.15 (DQ2)
/B_D3: J1.12, U2.17 (D3), U3.17 (DQ3), U4.17 (DQ3), U5.17 (DQ3)
/B_D4: J1.10, U2.18 (D4), U3.18 (DQ4), U4.18 (DQ4), U5.18 (DQ4)
/B_D5: J1.8, U2.19 (D5), U3.19 (DQ5), U4.19 (DQ5), U5.19 (DQ5)
/B_D6: J1.6, U2.20 (D6), U3.20 (DQ6), U4.20 (DQ6), U5.20 (DQ6)
/B_D7: J1.4, U2.21 (D7), U3.21 (DQ7), U4.21 (DQ7), U5.21 (DQ7)
/GND: C1.2, C2.2, C3.2, C4.2, C5.2, CP1.2, CP2.2, D1.1 (K), H1.1, H2.1, H3.1, H4.1, J1.1, J1.40, J2.1, J2.34, J3.2, J3.3, J4.1, J4.8, U1.8 (GND), U1.15 (E), U2.16 (GND), U3.16 (VSS), U4.16 (VSS), U5.16 (VSS)
/M_A14: J2.33, U2.29 (A14), U3.3 (A14), U4.3 (A14), U5.3 (A14)
/M_A15: J2.31, U2.3 (A15), U3.31 (A15), U4.31 (A15), U5.31 (A15)
/M_A16: J2.29, U2.2 (A16), U3.2 (A16), U4.2 (A16), U5.2 (A16)
/M_A17: J2.27, U2.30 (A17), U3.30 (A17), U4.30 (A17), U5.30 (A17)
/M_A18: J2.25, U2.1 (A18), U3.1 (A18), U4.1 (A18), U5.1 (A18)
/M_A19: J2.23, U1.2 (A0)
/M_A20: J2.21, U1.3 (A1)
/M_A21: J2.19, J5.1, U1.14 (A0)
/~BANK_ENABLE: J5.2, U1.1 (E)
/~MA_21: J5.3, U1.9 (O3)
/~MEMR: J4.3, U2.24 (OE), U3.24 (OE#), U4.24 (OE#), U5.24 (OE#)
/~MEMW: J4.4, U3.29 (WE#), U4.29 (WE#), U5.29 (WE#)
/~MEM_CS1: U1.4 (O0), U2.22 (CE)
/~MEM_CS2: U1.5 (O1), U3.22 (CE#)
/~MEM_CS3: U1.6 (O2), U4.22 (CE#)
/~MEM_CS4: U1.7 (O3), U5.22 (CE#)
unnamed: D1.2 (A), R1.2

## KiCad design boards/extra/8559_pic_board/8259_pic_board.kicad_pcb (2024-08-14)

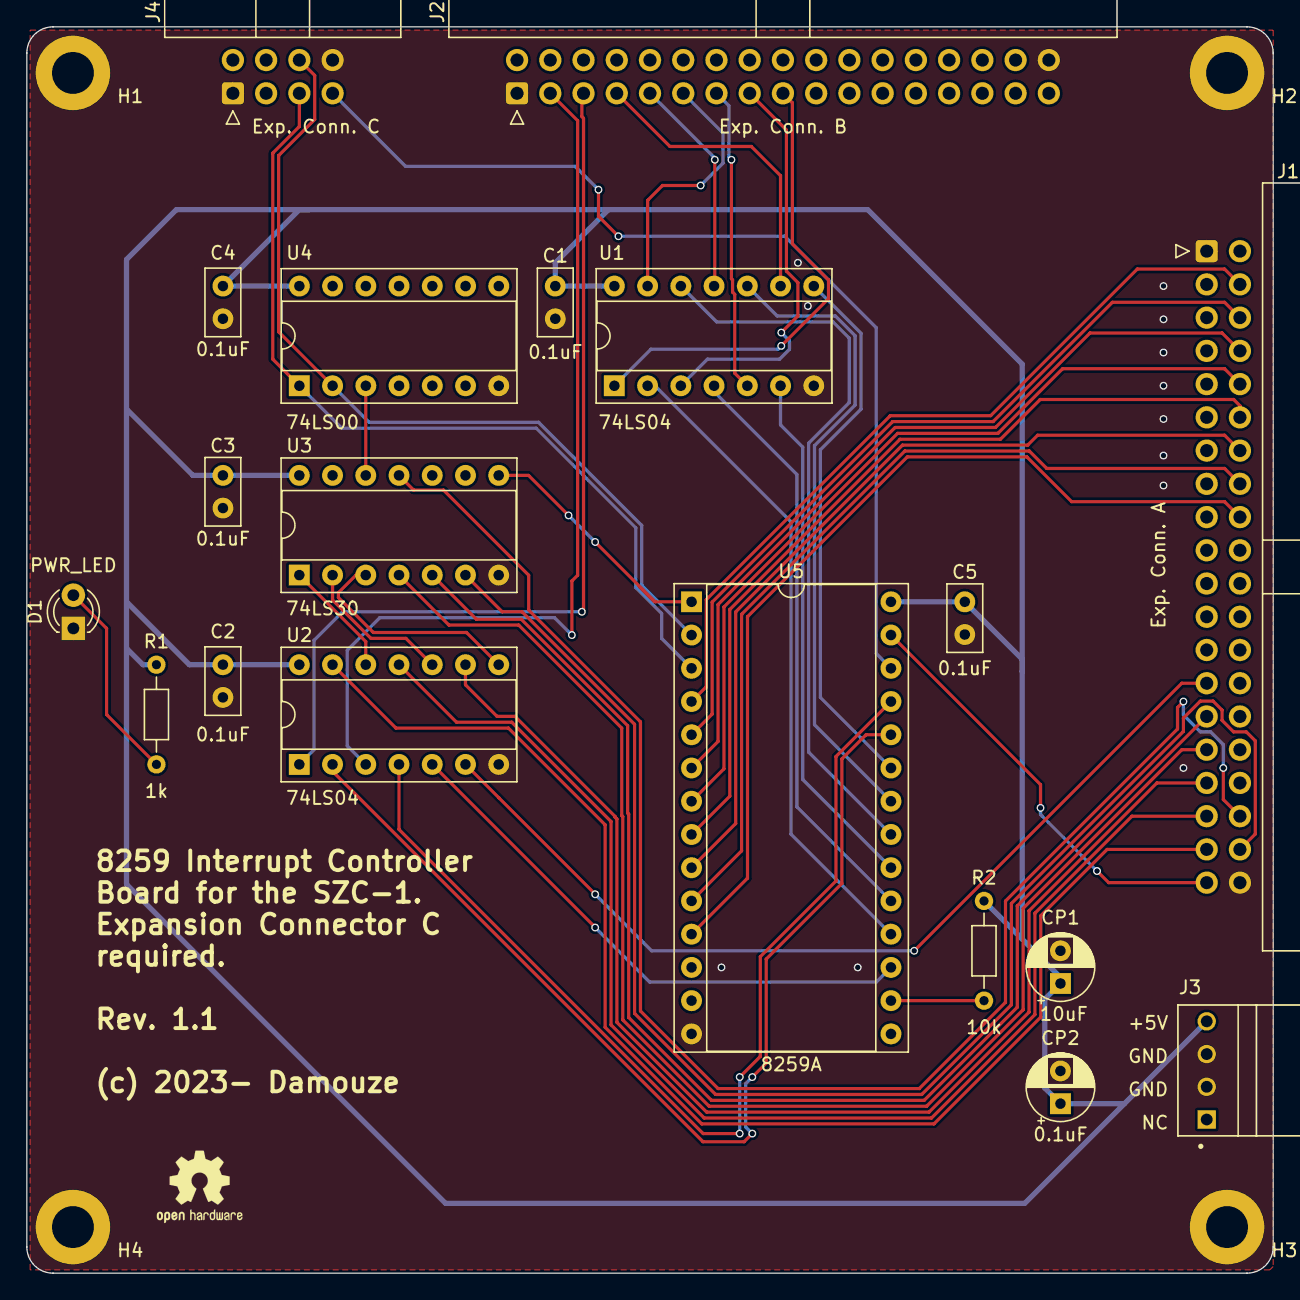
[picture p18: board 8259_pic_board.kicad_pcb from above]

Board: 2 copper layers, 95.2 x 95.2 mm, 23 parts (0 on the bottom side), 46 nets.

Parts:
C1, C2, C3, C4, C5: 0.1uF; C_Disc_D5.0mm_W2.5mm_P2.50mm
CP1: 10uF; CP_Radial_D5.0mm_P2.50mm
CP2: 0.1uF; CP_Radial_D5.0mm_P2.50mm
D1: PWR_LED; LED_D3.0mm
H1, H2, H3, H4: MountingHole_Pad; MountingHole_3.2mm_M3_ISO7380_Pad
J1: Exp. Conn. A; IDC-Header_2x20_P2.54mm_Horizontal
J2: Exp. Conn. B; IDC-Header_2x17_P2.54mm_Horizontal
J3: Power; TE_171826-4
J4: Exp. Conn. C; IDC-Header_2x04_P2.54mm_Horizontal
R1: 1k; R_Axial_DIN0204_L3.6mm_D1.6mm_P7.62mm_Horizontal
R2: 10k; R_Axial_DIN0204_L3.6mm_D1.6mm_P7.62mm_Horizontal
U1, U2: 74LS04; DIP-14_W7.62mm_Socket
U3: 74LS30; DIP-14_W7.62mm_Socket
U4: 74LS00; DIP-14_W7.62mm_Socket
U5: 8259A; DIP-28_W15.24mm_Socket

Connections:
/+5V: C1.1, C2.1, C3.1, C4.1, C5.1, CP1.1, CP2.1, J3.4, R1.1, R2.2, U1.14 (VCC), U2.14 (VCC), U3.14 (VCC), U4.14 (VCC), U5.28 (VCC)
/B_A0: J1.39, U5.27 (A0)
/B_A1: J1.37, U2.13
/B_A2: J1.35, U2.11
/B_A3: J1.33, U2.9
/B_A4: J1.31, U3.4
/B_A5: J1.29, U3.5
/B_A6: J1.38, U3.6
/B_A7: J1.36, U3.11
/B_D0: J1.18, U5.11 (D0)
/B_D1: J1.16, U5.10 (D1)
/B_D2: J1.14, U5.9 (D2)
/B_D3: J1.12, U5.8 (D3)
/B_D4: J1.10, U5.7 (D4)
/B_D5: J1.8, U5.6 (D5)
/B_D6: J1.6, U5.5 (D6)
/B_D7: J1.4, U5.4 (D7)
/CPU_INT: U2.5, U5.17 (INT)
/GND: C1.2, C2.2, C3.2, C4.2, C5.2, CP1.2, CP2.2, D1.1 (K), H1.1, H2.1, H3.1, H4.1, J1.1, J1.40, J2.1, J2.34, J3.2, J3.3, J4.1, J4.8, U1.7 (GND), U2.7 (GND), U3.7 (GND), U4.7 (GND), U5.14 (GND)
/INT0: U1.2, U5.18 (IR0)
/INT1: U1.4, U5.19 (IR1)
/INT2: U1.6, U5.20 (IR2)
/INT3: U1.12, U5.21 (IR3)
/INT4: U1.10, U5.22 (IR4)
/INT5: U1.8, U5.23 (IR5)
/INT6: U2.2, U5.24 (IR6)
/INT7: U2.4, U5.25 (IR7)
/~BA_1: U2.12, U3.1
/~BA_2: U2.10, U3.2
/~BA_3: U2.8, U3.3
/~INT0: J2.17, U1.1
/~INT1: J2.15, U1.3
/~INT2: J2.13, U1.5
/~INT3: J2.11, U1.13
/~INT4: J2.9, U1.11
/~INT5: J2.7, U1.9
/~INT6: J2.5, U2.1
/~INT7: J2.3, U2.3
/~INTA: J4.7, U5.26 (~INTA)
/~INT: J1.27, U2.6
/~IOR: J4.5, U4.1, U5.3 (~RD)
/~IOW: J4.6, U4.2, U5.2 (~WR)
/~IOXS: U3.12, U4.3
/~PIC_CS: U3.8, U5.1 (~CS)
/~PIC_PLUP: R2.1, U5.16 (~SP/~EN)
unnamed: D1.2 (A), R1.2

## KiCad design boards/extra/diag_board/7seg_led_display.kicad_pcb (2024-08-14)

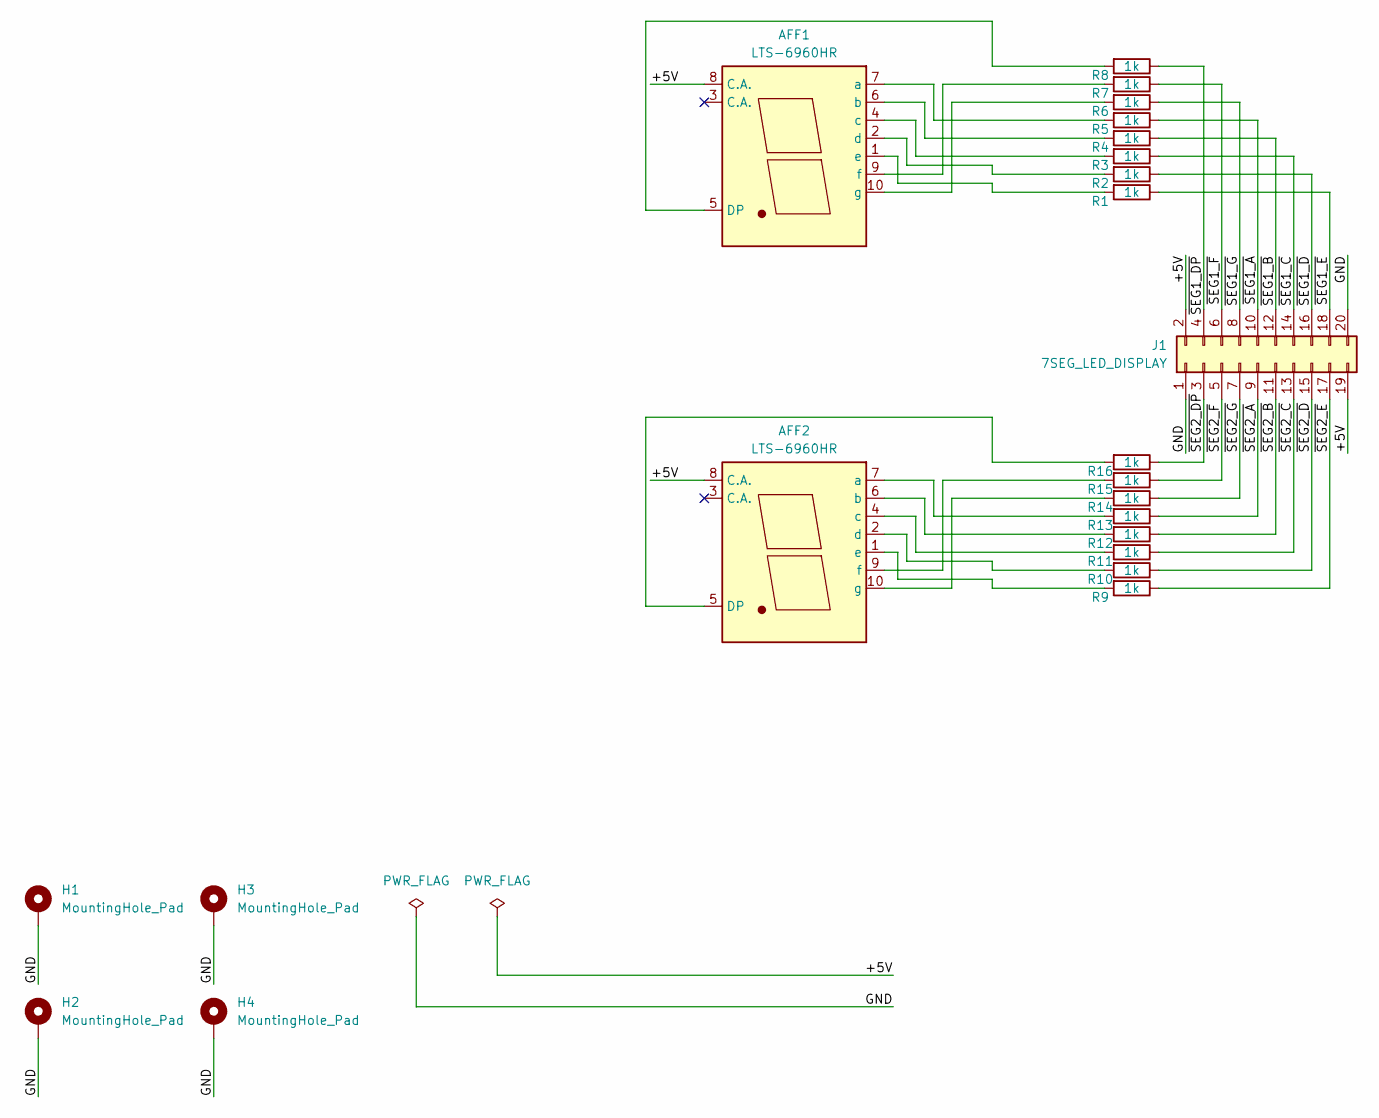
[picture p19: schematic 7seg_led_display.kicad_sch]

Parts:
AFF1, AFF2: LTS-6960HR; 7SegmentLED_LTS6760_LTS6780
H1, H2, H3, H4: MountingHole_Pad; MountingHole_3.2mm_M3_ISO7380_Pad
J1: 7SEG_LED_DISPLAY; PinSocket_2x10_P2.54mm_Vertical
R1, R2, R3, R4, R5, R6, R7, R8, R9, R10, R11, R12, R13, R14, R15, R16: 1k; R_Axial_DIN0204_L3.6mm_D1.6mm_P7.62mm_Horizontal

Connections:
/+5V: AFF1.8 (C.A.), AFF2.8 (C.A.), J1.2, J1.19
/GND: H1.1, H2.1, H3.1, H4.1, J1.1, J1.20
/~SEG1_A: J1.10, R5.1
/~SEG1_B: J1.12, R4.1
/~SEG1_C: J1.14, R3.1
/~SEG1_DP: J1.4, R8.1
/~SEG1_D: J1.16, R2.1
/~SEG1_E: J1.18, R1.1
/~SEG1_F: J1.6, R7.1
/~SEG1_G: J1.8, R6.1
/~SEG2_A: J1.9, R13.1
/~SEG2_B: J1.11, R12.1
/~SEG2_C: J1.13, R11.1
/~SEG2_DP: J1.3, R16.1
/~SEG2_D: J1.15, R10.1
/~SEG2_E: J1.17, R9.1
/~SEG2_F: J1.5, R15.1
/~SEG2_G: J1.7, R14.1
unnamed: AFF1.5 (DP), R8.2
unnamed: AFF1.7 (a), R5.2
unnamed: AFF1.6 (b), R4.2
unnamed: AFF1.4 (c), R3.2
unnamed: AFF1.2 (d), R2.2
unnamed: AFF1.1 (e), R1.2
unnamed: AFF1.9 (f), R7.2
unnamed: AFF1.10 (g), R6.2
unnamed: AFF2.5 (DP), R16.2
unnamed: AFF2.7 (a), R13.2
unnamed: AFF2.6 (b), R12.2
unnamed: AFF2.4 (c), R11.2
unnamed: AFF2.2 (d), R10.2
unnamed: AFF2.1 (e), R9.2
unnamed: AFF2.9 (f), R15.2
unnamed: AFF2.10 (g), R14.2

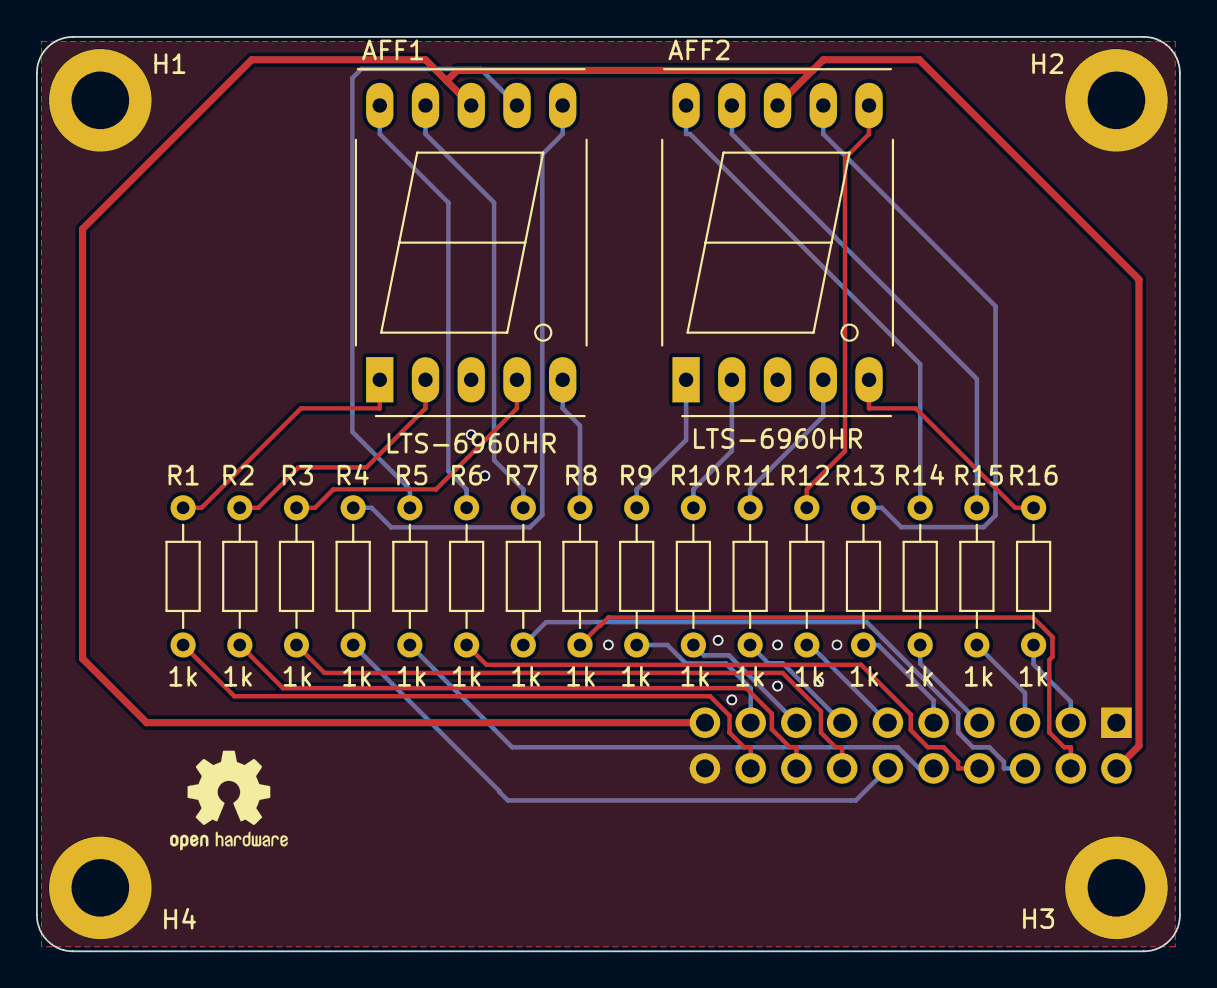
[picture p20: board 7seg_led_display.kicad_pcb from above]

Board: 2 copper layers, 63.5 x 50.8 mm, 23 parts (1 on the bottom side), 34 nets.

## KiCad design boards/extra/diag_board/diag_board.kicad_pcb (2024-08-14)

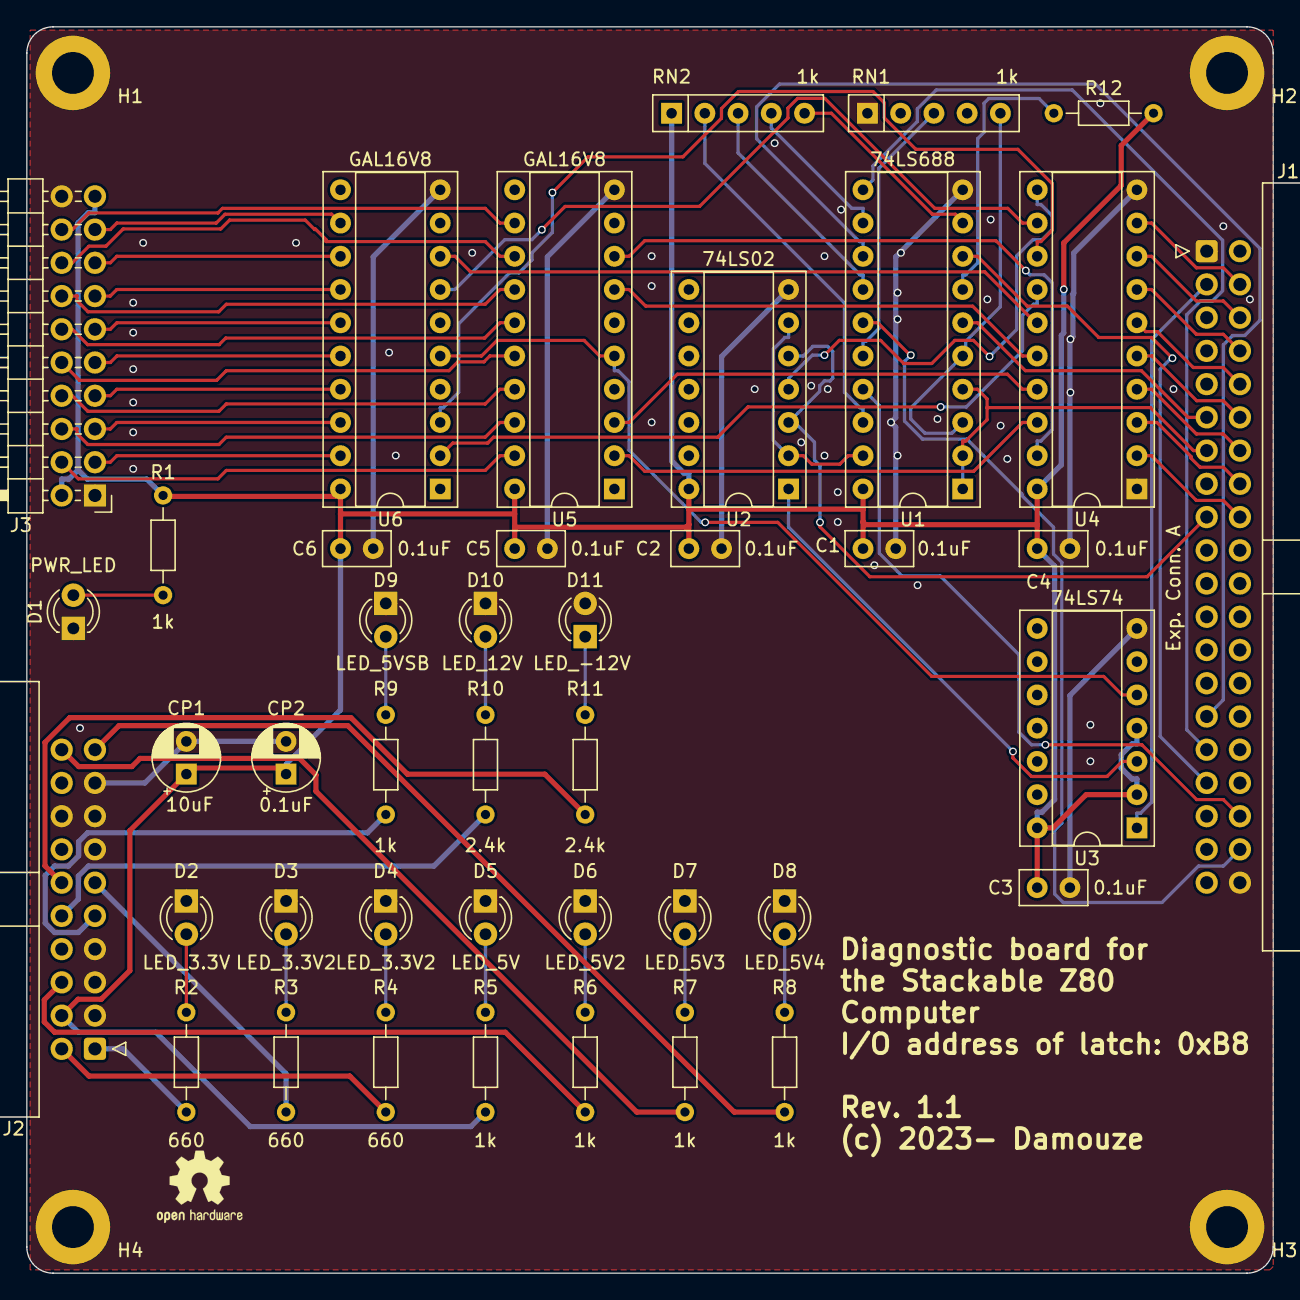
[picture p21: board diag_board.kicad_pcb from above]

Board: 2 copper layers, 95.2 x 95.2 mm, 46 parts (0 on the bottom side), 74 nets.

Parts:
C1, C2, C3, C4, C5, C6: 0.1uF; C_Disc_D5.0mm_W2.5mm_P2.50mm
CP1: 10uF; CP_Radial_D5.0mm_P2.50mm
CP2: 0.1uF; CP_Radial_D5.0mm_P2.50mm
D1: PWR_LED; LED_D3.0mm
D2: LED_3.3V; LED_D3.0mm
D3, D4: LED_3.3V2; LED_D3.0mm
D5: LED_5V; LED_D3.0mm
D6: LED_5V2; LED_D3.0mm
D7: LED_5V3; LED_D3.0mm
D8: LED_5V4; LED_D3.0mm
D9: LED_5VSB; LED_D3.0mm
D10: LED_12V; LED_D3.0mm
D11: LED_-12V; LED_D3.0mm
H1, H2, H3, H4: MountingHole_Pad; MountingHole_3.2mm_M3_ISO7380_Pad
J1: Exp. Conn. A; IDC-Header_2x20_P2.54mm_Horizontal
J2: Power; IDC-Header_2x10_P2.54mm_Horizontal
J3: 7SEG_LED_DISPLAY; PinHeader_2x10_P2.54mm_Horizontal
R1, R5, R6, R7, R8, R9, R12: 1k; R_Axial_DIN0204_L3.6mm_D1.6mm_P7.62mm_Horizontal
R2, R3, R4: 660; R_Axial_DIN0204_L3.6mm_D1.6mm_P7.62mm_Horizontal
R10, R11: 2.4k; R_Axial_DIN0204_L3.6mm_D1.6mm_P7.62mm_Horizontal
RN1, RN2: 1k; R_Array_SIP5
U1: 74LS688; DIP-20_W7.62mm_Socket
U2: 74LS02; DIP-14_W7.62mm_Socket
U3: 74LS74; DIP-14_W7.62mm_Socket
U4: 74LS573; DIP-20_W7.62mm_Socket
U5, U6: GAL16V8; DIP-20_W7.62mm_Socket

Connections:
/+3.3V: J2.1, R2.1
/+3.3V2: J2.2, R4.1
/+3.3V3: J2.11, R3.1
/+5V: C1.1, C2.1, C3.1, C4.1, C5.1, C6.1, CP1.1, CP2.1, J2.4, J3.2, J3.19, R1.1, R5.1, R12.2, RN2.1 (common), U1.20 (VCC), U2.14 (VCC), U3.2 (D), U3.4 (~S), U3.14 (VCC), U4.20 (VCC), U5.20 (VCC), U6.20 (VCC)
/+5V2: J2.6, R6.1
/+5V3: J2.20, R7.1
/+5V4: J2.19, R8.1
/+5VSB: J2.9, R9.1
/+12V: J2.10, R10.1
/-12V: J2.12, R11.1
/B_A3: J1.33, U1.8 (P3)
/B_A4: J1.31, U1.11 (P4)
/B_A5: J1.29, U1.13 (P5)
/B_A6: J1.38, U1.15 (P6)
/B_A7: J1.36, U1.17 (P7)
/B_D0: J1.18, U4.2 (D0)
/B_D1: J1.16, U4.3 (D1)
/B_D2: J1.14, U4.4 (D2)
/B_D3: J1.12, U4.5 (D3)
/B_D4: J1.10, U4.6 (D4)
/B_D5: J1.8, U4.7 (D5)
/B_D6: J1.6, U4.8 (D6)
/B_D7: J1.4, U4.9 (D7)
/DIAG_CS: U2.4, U4.11 (Load)
/GND: C1.2, C2.2, C3.2, C4.2, C5.2, C6.2, CP1.2, CP2.2, D1.1 (K), D2.1 (K), D3.1 (K), D4.1 (K), D5.1 (K), D6.1 (K), D7.1 (K), D8.1 (K), D9.1 (K), D10.1 (K), D11.2 (A), H1.1, H2.1, H3.1, H4.1, J1.1, J1.40, J2.3, J2.5, J2.7, J2.13, J2.15, J2.16, J2.17, J3.1, J3.20, RN1.1 (common), U1.10 (GND), U2.7 (GND), U3.7 (GND), U4.1 (OE), U4.10 (GND), U5.10 (GND), U6.10 (GND)
/I0: U4.19 (Q0), U5.8 (I8)
/I1: U4.18 (Q1), U5.2 (I2)
/I2: U4.17 (Q2), U5.3 (I3)
/I3: U4.16 (Q3), U5.7 (I7)
/I4: U4.15 (Q4), U6.8 (I8)
/I5: U4.14 (Q5), U6.2 (I2)
/I6: U4.13 (Q6), U6.3 (I3)
/I7: U4.12 (Q7), U6.7 (I7)
/L_CLK: U2.1, U3.3 (C)
/R_A3: RN2.5 (R4), U1.9 (R3)
/R_A4: RN2.4 (R3), U1.12 (R4)
/R_A5: RN2.3 (R2), U1.14 (R5)
/R_A6: RN1.3 (R2), U1.16 (R6)
/R_A7: RN2.2 (R1), U1.18 (R7)
/~BI: U3.5 (Q), U5.5 (I5), U6.5 (I5)
/~B_IORQ: J1.13, U1.1 (G), U1.2 (P0), U1.4 (P1)
/~B_M1: J1.11, U1.6 (P2)
/~B_WR: J1.17, U2.3, U2.5
/~DIAG_CS: U1.19 (P=R), U2.2, U2.6
/~RESET: J1.3, U3.1 (~R)
/~R_IORQ: RN1.5 (R4), U1.3 (R0), U1.5 (R1)
/~R_M1: R12.1, U1.7 (R2)
/~SEG1_A: J3.10, U5.16 (IO4)
/~SEG1_B: J3.12, U5.15 (IO5)
/~SEG1_C: J3.14, U5.14 (IO6)
/~SEG1_DP: J3.4, U5.19 (IO1)
/~SEG1_D: J3.16, U5.13 (IO7)
/~SEG1_E: J3.18, U5.12 (IO8)
/~SEG1_F: J3.6, U5.18 (IO2)
/~SEG1_G: J3.8, U5.17 (I03)
/~SEG2_A: J3.9, U6.16 (IO4)
/~SEG2_B: J3.11, U6.15 (IO5)
/~SEG2_C: J3.13, U6.14 (IO6)
/~SEG2_DP: J3.3, U6.19 (IO1)
/~SEG2_D: J3.15, U6.13 (IO7)
/~SEG2_E: J3.17, U6.12 (IO8)
/~SEG2_F: J3.5, U6.18 (IO2)
/~SEG2_G: J3.7, U6.17 (I03)
unnamed: D1.2 (A), R1.2
unnamed: D2.2 (A), R2.2
unnamed: D3.2 (A), R3.2
unnamed: D4.2 (A), R4.2
unnamed: D5.2 (A), R5.2
unnamed: D6.2 (A), R6.2
unnamed: D7.2 (A), R7.2
unnamed: D8.2 (A), R8.2
unnamed: D9.2 (A), R9.2
unnamed: D10.2 (A), R10.2
unnamed: D11.1 (K), R11.2

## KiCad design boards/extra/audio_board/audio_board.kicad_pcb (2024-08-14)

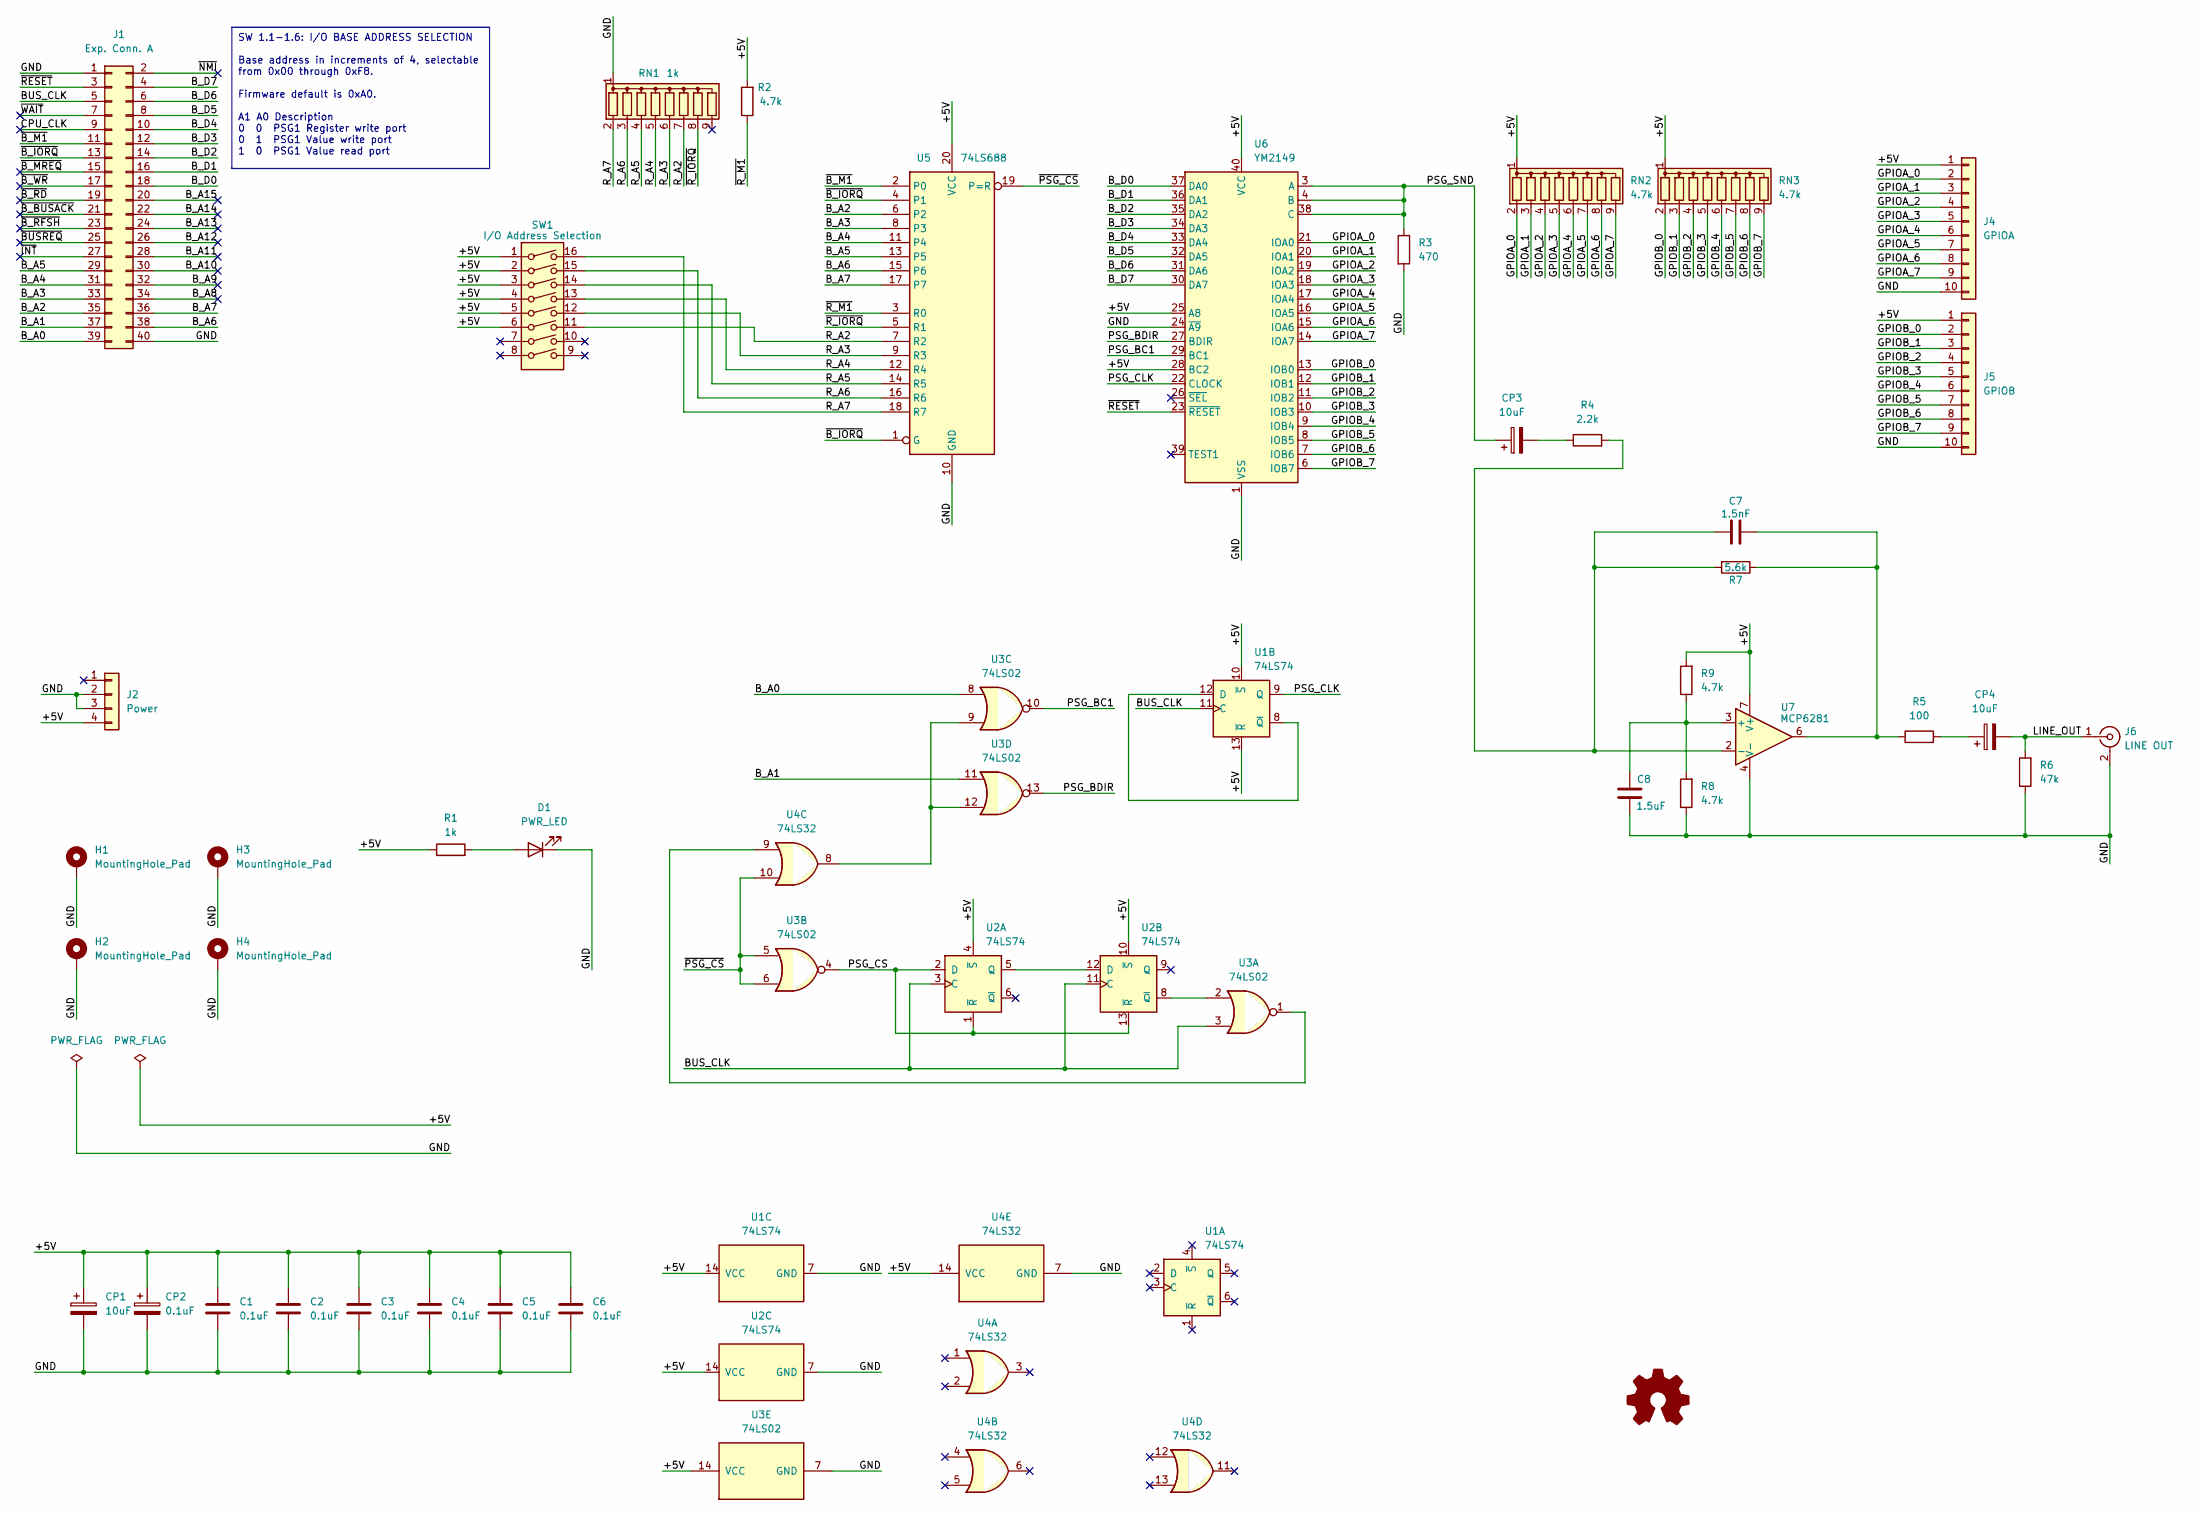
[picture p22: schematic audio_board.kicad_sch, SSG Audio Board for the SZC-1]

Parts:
C1, C2, C3, C4, C5, C6: 0.1uF; C_Disc_D5.0mm_W2.5mm_P2.50mm
C7: 1.5nF; C_Axial_L3.8mm_D2.6mm_P7.50mm_Horizontal
C8: 1.5uF; C_Axial_L3.8mm_D2.6mm_P7.50mm_Horizontal
CP1, CP3, CP4: 10uF; CP_Radial_D5.0mm_P2.50mm
CP2: 0.1uF; CP_Radial_D5.0mm_P2.50mm
D1: PWR_LED; LED_D3.0mm
H1, H2, H3, H4: MountingHole_Pad; MountingHole_3.2mm_M3_ISO7380_Pad
J1: Exp. Conn. A; IDC-Header_2x20_P2.54mm_Horizontal
J2: Power; TE_171826-4
J4: GPIOA; PinSocket_1x10_P2.54mm_Horizontal
J5: GPIOB; PinSocket_1x10_P2.54mm_Horizontal
J6: LINE OUT; CUI_RCJ-041
R1: 1k; R_Axial_DIN0204_L3.6mm_D1.6mm_P7.62mm_Horizontal
R2, R8, R9: 4.7k; R_Axial_DIN0204_L3.6mm_D1.6mm_P7.62mm_Horizontal
R3: 470; R_Axial_DIN0204_L3.6mm_D1.6mm_P7.62mm_Horizontal
R4: 2.2k; R_Axial_DIN0204_L3.6mm_D1.6mm_P7.62mm_Horizontal
R5: 100; R_Axial_DIN0204_L3.6mm_D1.6mm_P7.62mm_Horizontal
R6: 47k; R_Axial_DIN0204_L3.6mm_D1.6mm_P7.62mm_Horizontal
R7: 5.6k; R_Axial_DIN0204_L3.6mm_D1.6mm_P7.62mm_Horizontal
RN1: 1k; R_Array_SIP9
RN2, RN3: 4.7k; R_Array_SIP9
SW1: I/O Address Selection; SW_DIP_SPSTx08_Slide_6.7x21.88mm_W7.62mm_P2.54mm_LowProfile
U1, U2: 74LS74; DIP-14_W7.62mm_Socket
U3: 74LS02; DIP-14_W7.62mm_Socket
U4: 74LS32; DIP-14_W7.62mm_Socket
U5: 74LS688; DIP-20_W7.62mm_Socket
U6: YM2149; DIP-40_W15.24mm_Socket
U7: MCP6281; DIP-8_W7.62mm_Socket

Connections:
/+5V: C1.1, C2.1, C3.1, C4.1, C5.1, C6.1, CP1.1, CP2.1, J2.4, J4.1, J5.1, R1.1, R2.2, R9.2, RN2.1 (common), RN3.1 (common), SW1.1, SW1.2, SW1.3, SW1.4, SW1.5, SW1.6, U1.10 (~S), U1.13 (~R), U1.14 (VCC), U2.4 (~S), U2.10 (~S), U2.14 (VCC), U3.14 (VCC), U4.14 (VCC), U5.20 (VCC), U6.25 (A8), U6.28 (BC2), U6.40 (VCC), U7.7 (V+)
/BUS_CLK: J1.5, U1.11 (C), U2.3 (C), U2.11 (C), U3.3
/B_A0: J1.39, U3.8
/B_A1: J1.37, U3.11
/B_A2: J1.35, U5.6 (P2)
/B_A3: J1.33, U5.8 (P3)
/B_A4: J1.31, U5.11 (P4)
/B_A5: J1.29, U5.13 (P5)
/B_A6: J1.38, U5.15 (P6)
/B_A7: J1.36, U5.17 (P7)
/B_A8: J1.34
/B_A9: J1.32
/B_A10: J1.30
/B_A11: J1.28
/B_A12: J1.26
/B_A13: J1.24
/B_A14: J1.22
/B_A15: J1.20
/B_D0: J1.18, U6.37 (DA0)
/B_D1: J1.16, U6.36 (DA1)
/B_D2: J1.14, U6.35 (DA2)
/B_D3: J1.12, U6.34 (DA3)
/B_D4: J1.10, U6.33 (DA4)
/B_D5: J1.8, U6.32 (DA5)
/B_D6: J1.6, U6.31 (DA6)
/B_D7: J1.4, U6.30 (DA7)
/CPU_CLK: J1.9
/GND: C1.2, C2.2, C3.2, C4.2, C5.2, C6.2, C8.1, CP1.2, CP2.2, D1.1 (K), H1.1, H2.1, H3.1, H4.1, J1.1, J1.40, J2.2, J2.3, J4.10, J5.10, J6.2 (Ext), R3.2, R6.1, R8.1, RN1.1 (common), U1.7 (GND), U2.7 (GND), U3.7 (GND), U4.7 (GND), U5.10 (GND), U6.1 (VSS), U6.24 (~A9), U7.4 (V-)
/GPIOA_0: J4.2, RN2.2 (R1), U6.21 (IOA0)
/GPIOA_1: J4.3, RN2.3 (R2), U6.20 (IOA1)
/GPIOA_2: J4.4, RN2.4 (R3), U6.19 (IOA2)
/GPIOA_3: J4.5, RN2.5 (R4), U6.18 (IOA3)
/GPIOA_4: J4.6, RN2.6 (R5), U6.17 (IOA4)
/GPIOA_5: J4.7, RN2.7 (R6), U6.16 (IOA5)
/GPIOA_6: J4.8, RN2.8 (R7), U6.15 (IOA6)
/GPIOA_7: J4.9, RN2.9 (R8), U6.14 (IOA7)
/GPIOB_0: J5.2, RN3.2 (R1), U6.13 (IOB0)
/GPIOB_1: J5.3, RN3.3 (R2), U6.12 (IOB1)
/GPIOB_2: J5.4, RN3.4 (R3), U6.11 (IOB2)
/GPIOB_3: J5.5, RN3.5 (R4), U6.10 (IOB3)
/GPIOB_4: J5.6, RN3.6 (R5), U6.9 (IOB4)
/GPIOB_5: J5.7, RN3.7 (R6), U6.8 (IOB5)
/GPIOB_6: J5.8, RN3.8 (R7), U6.7 (IOB6)
/GPIOB_7: J5.9, RN3.9 (R8), U6.6 (IOB7)
/LINE_OUT: CP4.2, J6.1 (In), R6.2
/PSG_BC1: U3.10, U6.29 (BC1)
/PSG_BDIR: U3.13, U6.27 (BDIR)
/PSG_CLK: U1.9 (Q), U6.22 (CLOCK)
/PSG_CS: U2.1 (~R), U2.2 (D), U2.13 (~R), U3.4
/PSG_SND: CP3.1, R3.1, U6.3 (A), U6.4 (B), U6.38 (C)
/R_A2: RN1.7 (R6), SW1.11, U5.7 (R2)
/R_A3: RN1.6 (R5), SW1.12, U5.9 (R3)
/R_A4: RN1.5 (R4), SW1.13, U5.12 (R4)
/R_A5: RN1.4 (R3), SW1.14, U5.14 (R5)
/R_A6: RN1.3 (R2), SW1.15, U5.16 (R6)
/R_A7: RN1.2 (R1), SW1.16, U5.18 (R7)
/~BUSREQ: J1.25
/~B_BUSACK: J1.21
/~B_IORQ: J1.13, U5.1 (G), U5.4 (P1)
/~B_M1: J1.11, U5.2 (P0)
/~B_MREQ: J1.15
/~B_RD: J1.19
/~B_RFSH: J1.23
/~B_WR: J1.17
/~INT: J1.27
/~NMI: J1.2
/~PSG_CS: U3.5, U3.6, U4.10, U5.19 (P=R)
/~RESET: J1.3, U6.23 (~RESET)
/~R_IORQ: RN1.8 (R7), U5.5 (R1)
/~R_M1: R2.1, U5.3 (R0)
/~WAIT: J1.7
unnamed: C7.1, R5.1, R7.1, U7.6
unnamed: CP3.2, R4.1
unnamed: CP4.1, R5.2
unnamed: D1.2 (A), R1.2
unnamed: U1.8 (~Q), U1.12 (D)
unnamed: U2.5 (Q), U2.12 (D)
unnamed: U2.8 (~Q), U3.2
unnamed: U3.1, U4.9
unnamed: U3.9, U3.12, U4.8
unnamed: C8.2, R8.2, R9.1, U7.3 (+)
unnamed: C7.2, R4.2, R7.2, U7.2 (-)

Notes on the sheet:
SW 1.1-1.6: I/O BASE ADDRESS SELECTION Base address in increments of 4, selectable from 0x00 through 0xF8. Firmware default is 0xA0. A1 A0 Description 0 0 PSG1 Register write port 0 1 PSG1 Value write port 1 0 PSG1 Value read port


Board: 2 copper layers, 95.2 x 95.2 mm, 42 parts (0 on the bottom side), 64 nets.

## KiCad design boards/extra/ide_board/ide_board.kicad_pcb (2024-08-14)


Board: 2 copper layers, 95.2 x 95.2 mm, 26 parts (0 on the bottom side), 71 nets.

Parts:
C1, C2, C3, C4: 0.1uF; C_Disc_D5.0mm_W2.5mm_P2.50mm
CP1: 10uF; CP_Radial_D5.0mm_P2.50mm
CP2: 0.1uF; CP_Radial_D5.0mm_P2.50mm
D1: PWR_LED; LED_D3.0mm
D2: HDD_LED; LED_D3.0mm
H1, H2, H3, H4: MountingHole_Pad; MountingHole_3.2mm_M3_ISO7380_Pad
J1: Exp. Conn. A; IDC-Header_2x20_P2.54mm_Horizontal
J2: Exp. Conn. B; IDC-Header_2x17_P2.54mm_Horizontal
J3: Power; TE_171826-4
J4: IDE; IDC-Header_2x20_P2.54mm_Vertical
R1, R3: 1k; R_Axial_DIN0204_L3.6mm_D1.6mm_P7.62mm_Horizontal
R2: 4.7k; R_Axial_DIN0204_L3.6mm_D1.6mm_P7.62mm_Horizontal
RN1: 1k; R_Array_SIP9
SW1: IRQ Selection; SW_DIP_SPSTx04_Slide_9.78x12.34mm_W7.62mm_P2.54mm
SW2: I/O Address Selection; SW_DIP_SPSTx08_Slide_6.7x21.88mm_W7.62mm_P2.54mm_LowProfile
U1: 74LS138; DIP-16_W7.62mm_Socket
U2: 74LS04; DIP-14_W7.62mm_Socket
U3: 74LS688; DIP-20_W7.62mm_Socket
U4: 82C55A; DIP-40_W15.24mm_Socket

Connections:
/+5V: C1.1, C2.1, C3.1, C4.1, CP1.1, CP2.1, J3.4, J4.38, R1.1, R2.2, R3.1, SW1.2, SW1.3, SW1.4, SW2.1, SW2.2, SW2.3, SW2.4, SW2.5, SW2.6, U1.6 (E3), U1.16 (VCC), U2.14 (VCC), U3.20 (VCC), U4.26 (VCC)
/B_A0: J1.39, U4.9 (A0)
/B_A1: J1.37, U4.8 (A1)
/B_A2: J1.35, U3.6 (P2)
/B_A3: J1.33, U3.8 (P3)
/B_A4: J1.31, U3.11 (P4)
/B_A5: J1.29, U3.13 (P5)
/B_A6: J1.38, U3.15 (P6)
/B_A7: J1.36, U3.17 (P7)
/B_D0: J1.18, U4.34 (D0)
/B_D1: J1.16, U4.33 (D1)
/B_D2: J1.14, U4.32 (D2)
/B_D3: J1.12, U4.31 (D3)
/B_D4: J1.10, U4.30 (D4)
/B_D5: J1.8, U4.29 (D5)
/B_D6: J1.6, U4.28 (D6)
/B_D7: J1.4, U4.27 (D7)
/GND: C1.2, C2.2, C3.2, C4.2, CP1.2, CP2.2, D1.1 (K), H1.1, H2.1, H3.1, H4.1, J1.1, J1.40, J2.1, J2.34, J3.2, J3.3, J4.2, J4.19, J4.21, J4.22, J4.24, J4.26, J4.30, J4.40, RN1.1 (common), U1.8 (GND), U2.7 (GND), U3.10 (GND), U4.7 (GND)
/HA0: J4.35, U4.14 (PC0)
/HA1: J4.33, U4.15 (PC1)
/HA2: J4.36, U4.16 (PC2)
/HD0: J4.17, U4.4 (PA0)
/HD1: J4.15, U4.3 (PA1)
/HD2: J4.13, U4.2 (PA2)
/HD3: J4.11, U4.1 (PA3)
/HD4: J4.9, U4.40 (PA4)
/HD5: J4.7, U4.39 (PA5)
/HD6: J4.5, U4.38 (PA6)
/HD7: J4.3, U4.37 (PA7)
/HD8: J4.4, U4.18 (PB0)
/HD9: J4.6, U4.19 (PB1)
/HD10: J4.8, U4.20 (PB2)
/HD11: J4.10, U4.21 (PB3)
/HD12: J4.12, U4.22 (PB4)
/HD13: J4.14, U4.23 (PB5)
/HD14: J4.16, U4.24 (PB6)
/HD15: J4.18, U4.25 (PB7)
/HDD_LED: D2.1 (K), J4.39
/IDE_RESET: U2.4, U4.35 (RESET)
/IRQ: J4.31, U2.1
/IRQ0_S: SW1.5, U1.1 (A0)
/IRQ1_S: SW1.6, U1.2 (A1)
/IRQ2_S: SW1.7, U1.3 (A2)
/R_A2: RN1.9 (R8), SW2.11, U3.7 (R2)
/R_A3: RN1.8 (R7), SW2.12, U3.9 (R3)
/R_A4: RN1.7 (R6), SW2.13, U3.12 (R4)
/R_A5: RN1.4 (R3), SW2.14, U3.14 (R5)
/R_A6: RN1.3 (R2), SW2.15, U3.16 (R6)
/R_A7: RN1.2 (R1), SW2.16, U3.18 (R7)
/~B_IORQ: J1.13, U3.1 (G), U3.4 (P1)
/~B_M1: J1.11, U3.2 (P0)
/~B_RD: J1.19, U4.36 (~WR)
/~B_WR: J1.17, U4.5 (~RD)
/~HCS0: J4.37, U4.12 (PC5)
/~HRD: J4.25, U4.10 (PC7)
/~HWR: J4.23, U4.11 (PC6)
/~IDE_CS: U3.19 (P=R), U4.6 (~CS)
/~INT1: J2.15, U1.14 (O1)
/~INT2: J2.13, U1.13 (O2)
/~INT3: J2.11, U1.12 (O3)
/~INT4: J2.9, U1.11 (O4)
/~INT5: J2.7, U1.10 (O5)
/~INT6: J2.5, U1.9 (O6)
/~INT7: J2.3, U1.7 (O7)
/~INT: J1.27, U1.15 (O0)
/~IRQ: U1.4 (E1), U1.5 (E2), U2.2
/~RESET: J1.3, J4.1, U2.3
/~R_IORQ: RN1.5 (R4), U3.5 (R1)
/~R_M1: R2.1, U3.3 (R0)
unnamed: D1.2 (A), R1.2
unnamed: D2.2 (A), R3.2

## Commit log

2023-10-09 Initial commit.
    [20230911_power_board_BOM_PCBWay.xlsx, 7seg_led_display.dsn, 7seg_led_display.kicad_pcb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]
2023-10-09 Moved boards/rom_ram_board_2MB to boards/extra/rom_ram_board_2MB
2023-10-14 Removed BOM-files received from PCBWay.
    [20230911_power_board_BOM_PCBWay.xlsx, T-3FR12W337658A-3sets-pcbway_outside_bom_1534322256351(2023-09-12).xls]
2023-10-14 Generated interactive BOMs for most boards.
    [diag_board.kicad_pcb, even_simpler_z80.kicad_pcb, msx_rom_ram_board.kicad_pcb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]
2023-12-30 * Working on new powerdistribution method.
    [clock_reset.kicad_sch, even_simpler_z80.kicad_pcb, even_simpler_z80.kicad_sch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]
2024-03-14 Added expansion connector C and designed some new boards around it.
    [8259_pic_board.kicad_pcb, 8259_pic_board.kicad_sch, bom.csv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]
2024-03-14 Added new expansion connector C.
    [msx_slots.kicad_pcb, msx_slots.kicad_sch, ppi_slot_select_expanded.kicad_sch]
2024-03-14 Added audio board.
    [audio_board.kicad_pcb, audio_board.kicad_sch]
2024-03-15 Removed CPU connection A14 and A15 from Expansion Bus Connector B.
    [clock_reset.kicad_sch, cpu_board_ext_bus_v2.kicad_pcb, cpu_board_ext_bus_v2.kicad_sch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]
2024-03-16 Added 128kB ROM/RAM board v2.
    [rom_ram_board_128kB_v2.kicad_pcb, rom_ram_board_128kB_v2.kicad_sch]
2024-04-24 Preparation for ordering with PCBWay.
    [clock_reset.kicad_sch, cpu_board_ext_bus_v2.kicad_pcb, cpu_board_ext_bus_v2.kicad_sch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]
2024-04-24 Preparation for assembly order with PCBWay
    [serial_io_board.kicad_pcb, serial_io_board.kicad_sch]
2024-04-25 Changed footprint of D2 to DO-35.
    [clock_reset.kicad_sch, cpu_board_ext_bus_v2.kicad_pcb]
2024-08-14 Updated ROM/RAM Board V2
    Updated the ROM/RAM Board V2 to revision 1.1
    [rom_ram_board_v2-B_Adhesive.gbr, rom_ram_board_v2-B_Cu.gbr, rom_ram_board_v2-B_Fab.gbr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]
2024-08-14 Updated CPU board V2 with extension bus
    [PCBWay_bom.csv, PCBWay_positions.csv, bom.csv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]
2024-08-14 Added Poweboard V2
    Added Powerboard V2, which has power-on circuitry onboard.
    [20230911_power_board_BOM_PCBWay.xlsx, bom.csv, designators.csv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]
2024-08-14 Added new IBOMs
    [power_board_v2.kicad_pcb]
2024-08-14 Added Simple I/O board
    [simple_io_board-B_Adhesive.gbr, simple_io_board-B_Cu.gbr, simple_io_board-B_Fab.gbr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]
2024-08-14 Updated IDE board
    [ide_board.kicad_pcb, ide_board.kicad_sch]
2024-08-14 Updated Audio board
    [audio_board.kicad_pcb, audio_board.kicad_sch]
2024-08-14 Updated diag board
    [7seg_led_display.dsn, 7seg_led_display.kicad_pcb, 7seg_led_display.kicad_sch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]
2024-08-14 Updated PIC board
    [8259_pic_board.kicad_pcb, 8259_pic_board.kicad_sch]
2024-09-09 Updated serial I/O board last weekend.
    [cpu_board_ext_bus_v2.kicad_pcb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]
2025-08-22 Genera update of renderings and specifications
    [memmap.xlsx, memmap_noslots.xlsx]
2025-08-22 Extended CPU board update
    [clock_reset.kicad_sch, cpu_board_ext_bus_v2.kicad_pcb, cpu_board_ext_bus_v2.kicad_sch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]

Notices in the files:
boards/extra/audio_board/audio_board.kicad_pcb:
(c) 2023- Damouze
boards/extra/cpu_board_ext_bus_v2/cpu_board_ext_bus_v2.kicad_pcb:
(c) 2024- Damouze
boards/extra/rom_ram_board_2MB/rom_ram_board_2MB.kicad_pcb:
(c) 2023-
